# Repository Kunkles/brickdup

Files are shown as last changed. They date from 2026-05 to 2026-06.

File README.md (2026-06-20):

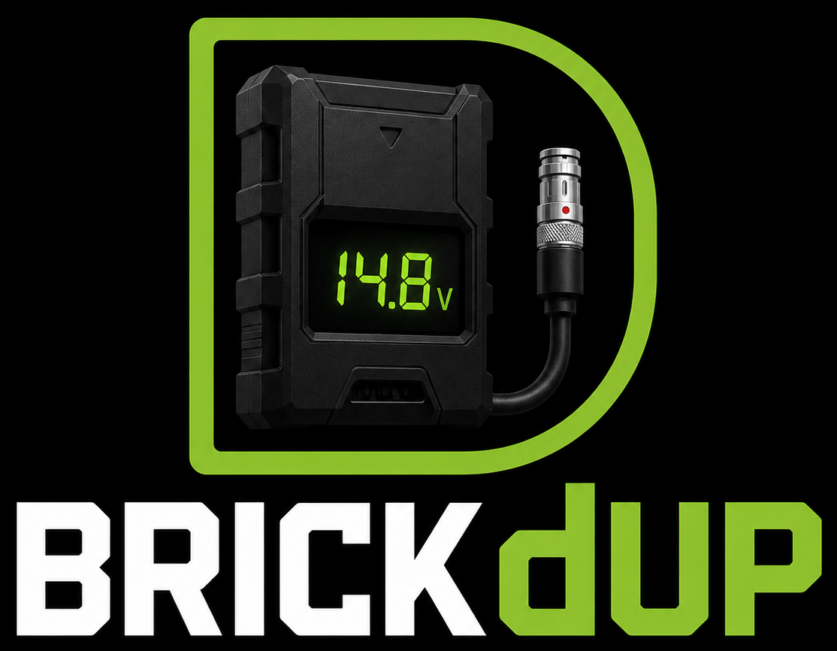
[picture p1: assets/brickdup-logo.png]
brickdup


# brickdup

Wireless battery voltage monitor for film/video sets. LoRa sensor nodes tap into camera batteries and broadcast readings to a handheld receiver with an e-ink display.

## Hardware

All boards: **Heltec WiFi LoRa 32 V3** (ESP32-S3 + SX1262, 915 MHz)

Receiver also has: **Waveshare 2.13" e-Paper HAT V4** (250×122, GDEY0213B74)

### Sensor node variants

| Variant | Battery | Connector | Voltage range | Divider |
|---|---|---|---|---|
| Onboard (`OB`) | 4S Li-Ion | D-Tap or AB 4-pin | up to 16.8V | R1=100kΩ, R2=22kΩ |
| Block (`BL`) | 6S Li-Ion | AB 4-pin (inline) | up to 25.2V | R1=180kΩ, R2=27kΩ |

Voltage divider feeds GPIO7. A 100nF ceramic cap between GPIO7 and GND filters ADC noise. Power the MCU through a buck converter (Pololu D24V10F5 — 36V max input, 5V out) tapped off VBAT. **Do not feed VBAT directly to the Heltec USB or VIN pin.**

📐 **Full wiring (both variants, with diagrams): [WIRING.md](WIRING.md)**
📌 **Pin assignments, button controls & screen layouts: [REFERENCE.md](REFERENCE.md)**
📝 **Firmware version history: [CHANGELOG.md](CHANGELOG.md)** — current: **v0.5.9**

### Pin map

```
LoRa SX1262 (HSPI):   CS=8, DIO1=14, RST=12, BUSY=13 | SCK=9, MISO=11, MOSI=10
ADC (sensor nodes):   VBAT_PIN = GPIO7 (ADC1_CH6)
E-ink (receiver):     CS=5, DC=4, RST=3, BUSY=2 | SCK=6, MOSI=1
```

## Sketches

| File | Flash to |
|---|---|
| **`sensor_universal_heltec_v3/`** | **Recommended** node firmware — one board, 4S **or** 6S, type selectable |
| `sensor_onboard_heltec_v3/` | Legacy onboard-only (4S) node |
| `sensor_block_heltec_v3/` | Legacy block-only (6S) node |
| `receiver_wireless_paper_v1_2/` | The handheld receiver (Heltec Wireless Paper) |
| `bench_ping_test/` | Both V3s, to verify the radio link (set `ROLE_PINGER` per board) |

**Universal node** (`sensor_universal_heltec_v3`) replaces the two single-mode
sketches: one universal divider (200k/22k as built — 2×100k + 22k — 6S-safe with headroom) and a runtime **battery
type** (OB 4S / BL 6S) that sets the thresholds + broadcast type. Pick it on the
config page or **long-press PRG** to toggle. Identical firmware on every node —
no per-unit edits. It shows a big 7-segment voltage and the type in the corner.

> **USB test mode:** the node sketches have `USB_TEST_MODE` (default `1`) that
> reads the board's onboard supply (~4V) instead of the divider, so the
> TX → RX → e-ink chain can be validated over USB-C with nothing wired. Set to
> `0` for real monitoring.

## Node identity

Every node has two names:

- **Permanent id** — auto-derived from the chip's unique MAC at boot. Never
  changes, guaranteed unique, and is the WiFi network name + the receiver's
  tracking key. The **universal** sketch uses a type-independent `ND-7F3A` (so
  toggling battery type updates the node in place); the legacy OB/BL sketches
  use `OB-7F3A` / `BL-7F3A`.
- **User name** — the friendly label you assign over WiFi (`Cam A`). Defaults to
  the permanent id until set. Shown on the OLED + handheld and broadcast.

Because the permanent id comes from the silicon, you flash the **same firmware to
every node** — no per-unit edits. With the universal sketch even the battery
type is a runtime setting, so one firmware truly covers every node.

## Packet format

```
T:<type>,I:<permId>,V:<voltage>,S:<status>[,B:<lipo>][,M:<name>]
```

Example: `T:OB,I:OB-7F3A,V:14.73,S:0,B:3.95,M:Cam A`

- `type` — `OB` or `BL`
- `permId` — permanent unique id (chip-derived), receiver's tracking key
- `voltage` — float, 2 decimal places
- `status` — 0=OK, 1=WARN, 2=CRIT, 3=no source (camera battery removed/dead)
- `lipo` — node bridge-LiPo voltage (optional; the node stays alive on it to report S:3)
- `name` — optional friendly name (no commas)

## Naming nodes (WiFi config portal)

Each node hosts a WiFi access point you can join to rename it — no reflashing:

1. Power the node and join WiFi **`Brickdup-OB-7F3A`** (password `brickdup`) —
   the suffix is unique per board, printed on the OLED at boot
2. Open **http://192.168.4.1**
3. Type a **name**, tap Save

The name persists in flash (survives reboot/reflash) and rides along in every
packet, so the handheld shows it automatically.

**Turning WiFi off (saves ~80mA):** no extra hardware needed —

- Tap the node's onboard **PRG button** any time to toggle WiFi on/off, or
- Hit **Turn off WiFi** on the config page when you're done naming.

Press PRG again to bring it back. The on/off choice is **remembered across
reboots** — a node switched off stays off after a power cycle. `WIFI_ON_AT_BOOT`
is only the first-ever-boot default.

## Button controls

| Unit | Single tap | Long press | Triple tap |
|---|---|---|---|
| Node (PRG) | toggle WiFi | — | **power off** |
| Receiver (USER) | page nodes | toggle dashboard | **power off** |

"Power off" is deep sleep (~10–20µA); the screen shows **POWERED DOWN** (white
on black), then **press the button again to wake** (the unit reboots). The
receiver e-ink keeps the POWERED DOWN screen visible while asleep.

Thresholds (defaults, editable per type in the node portal) — Onboard: WARN=13.5V, CRIT=12.8V | Block: WARN=21.0V, CRIT=20.0V

## Radio config

```
Frequency: 915.0 MHz  |  Bandwidth: 125 kHz  |  SF: 9  |  CR: 4/5
Sync word: 0xAB       |  TX power: 17 dBm    |  Preamble: 8
```

All nodes must use identical settings. SF9 gives 50–100m range with obstacles. Up to 12 nodes, 10s interval — no collision concern.

## Build environment

**Arduino IDE 2.x** with the **Heltec ESP32 board package** (Board Manager URL):
```
https://resource.heltec.cn/download/package_heltec_esp32_index.json
```

**Board selection differs per sketch** (the e-ink library requires the exact
board, or it errors with "Wrong build env"):

| Sketch | Tools → Board |
|---|---|
| `receiver_wireless_paper_v1_2` | **Wireless Paper** (search "paper") |
| `sensor_universal_heltec_v3` | Heltec WiFi LoRa 32(V3) |
| `sensor_onboard_heltec_v3` | Heltec WiFi LoRa 32(V3) |
| `sensor_block_heltec_v3` | Heltec WiFi LoRa 32(V3) |

Common settings: USB CDC On Boot → **Enabled** | Upload Speed → 921600

**OTA updates (no USB after the first flash):** every unit's web portal has a
`/update` page. Build a `.bin` via **Sketch → Export Compiled Binary**, join the
unit's WiFi, open its `/update` page (linked from the config page / dashboard),
and upload the matching `.bin` — it flashes the spare partition, verifies, and
reboots. Upload the OB `.bin` to onboard nodes, BL to block nodes, receiver to
the receiver (the page shows which it expects).

> No partition setting needed: the Heltec WiFi LoRa 32 V3 and Wireless Paper
> both default to the `default_8MB` scheme, which already has two ~3.3MB app
> slots (OTA-capable). There's no "Partition Scheme" menu for these boards
> because the partition is fixed — and it's the right one.

### Prebuilt firmware (CI)

GitHub Actions compiles all three sketches on **every push** and on version
tags — no local toolchain needed to get a `.bin`:

- **Every push:** download `brickdup-firmware` from the
  [latest Actions run](../../actions) (artifacts: `brickdup_onboard.bin`,
  `brickdup_block.bin`, `brickdup_receiver.bin`).
- **Tagged releases:** push a `vX.Y.Z` tag → the `.bin`s are attached to a
  [GitHub Release](../../releases).

Grab the matching `.bin` and push it to a unit via its `/update` page. To cut a
release: bump `FW_VERSION` in all three sketches, update `CHANGELOG.md`, commit,
then `git tag v0.5.1 && git push --tags`.

**Libraries (Library Manager):**
- `RadioLib` by Jan Gromeš — all three sketches
- `Heltec ESP32 Dev-Boards` by Heltec — node OLED (`HT_SSD1306Wire.h`)
- `heltec-eink-modules` by todd-herbert — receiver e-ink (pulls in Adafruit GFX)

## BOM

| Part | Source | ~Cost |
|---|---|---|
| Heltec WiFi LoRa 32 V3 (915 MHz) — nodes | Amazon | $22 ea |
| Heltec Wireless Paper (915 MHz) — receiver | Amazon | $22 |
| Pololu D24V10F5 buck converter (per node) | Pololu | — |
| Node LiPo — MakerHawk 1100mAh 1S (JST 1.25) | Amazon `B0F9YSFV4T` | 4-pack |
| Receiver LiPo — MakerFocus 3000mAh 1S (JST 1.25) | Amazon `B08T6GT7DV` | 4-pack |
| D-Tap male connectors | B&H (CT-DTAP-M) | — |
| AB 4-pin connectors | Pinknoise Systems / Trew Audio | — |
| 1% metal film resistors — universal: 200k, 27k (legacy: 100k/22k, 180k/27k) | — | — |
| 100nF ceramic caps (104) | — | — |

## Roadmap

- [x] Bench ping test (verify radio link before analog wiring)
- [x] Receiver paging (USER button cycles pages when >5 nodes)
- [x] Fuel gauge: SoC % + rough time-to-empty per node (voltage-based)
- [x] Calibration (enter true voltage on the web page; gain factor saved to NVS)
- [x] RSSI signal bars per node on the receiver
- [x] Receiver web dashboard (live node table on your phone; long-press USER)
- [x] OTA firmware update via the web portal on all units (/update page)
- [x] Captive portal — config page auto-pops on WiFi connect
- [x] Universal node — one sketch, runtime 4S/6S battery type (web or long-press)
- [x] Prebuilt firmware via CI (GitHub Actions builds .bin on every push)
- [ ] Channel/group selection — separate networks via distinct frequency +
      sync word per channel, set on the node web page and on the receiver,
      NVS-stored. Lets multiple brickdup systems coexist (e.g. 1st/2nd unit)
- [ ] WiFi client (STA) mode — units optionally join a local network (DHCP or
      static IP) instead of hosting their own AP, each reachable at a unique
      mDNS host like `brickdup-7f3a.local` (chip-serial based).
      Credentials set via the AP config page, stored in NVS. Reach/OTA any unit
      from one device on the production WiFi
- [ ] Trusted WiFi networks — a saved list of known SSIDs the unit auto-joins
      (STA) when one is in range and WiFi is on, falling back to its own AP
      otherwise. Set via the config page, stored in NVS
- [ ] BLE / companion phone app — receiver exposes node data over Bluetooth LE
      (GATT, mirroring the `/data` JSON) for a phone app: live view + push
      notifications for CRIT/DEAD batteries (alerts even with the handheld in a
      bag), no WiFi join needed. NimBLE stack; LoRa is a separate radio, BLE
      time-shares 2.4GHz with WiFi
- [ ] iOS app — native companion that keeps a **persistent live readout** of all
      nodes and fires **push/local notifications** on CRIT/DEAD/LOST (even when
      backgrounded or the phone is locked). Connects via BLE (Core Bluetooth
      background mode) to the receiver; the front-end for the BLE item above
- [ ] Bridge LiPo on nodes — small backup cell (buck keeps it charged) so a node
      stays alive to report a **camera battery removed/dead for sure** (vs just
      going silent), survives swaps, and reports its own LiPo level. Replaces the
      receiver's inferred DEAD with an explicit reported one
- [ ] VCLX block-battery mode (NiMH) — the blocks in use are Anton/Bauer
      **VCLX NM2** (600Wh **NiMH**), tapped at a 14.4V 4-pin XLR. Per the
      [manual](https://www.antonbauer.com/wp-content/uploads/2023/07/ab_86750174-4980_0-vclx_nm2-manual_en.pdf)
      spec table, only 28V/48V (+5V USB) are regulated; the 4-pin XLRs are
      **variable 12–17V** (pack-following) — so the node *does* see a real
      discharge curve. But the chemistry breaks the Li-ion fuel gauge: NiMH
      holds a flat ~14.4V (1.2V/cell × 12) for most of the discharge, knees
      at ~13.2V, and the battery hard-cuts its output at **12.0V** (output
      vanishes → bridge LiPo keeps the node alive to report DEAD). Repurpose
      BL mode → NiMH profile: thresholds ≈ WARN 13.2 / CRIT 12.4, and
      suppress SoC%/time-to-empty (or fit a rough NiMH curve) — the Li-ion
      curve reads nonsense on the flat middle. Verify thresholds on a real
      pack: meter the XLR full (~16.8V) vs drained. Heads-up for the divider
      bench test: cap input at ~17V for this mode, not 25.2V
- [ ] CRIT buzzer alert on receiver
- [x] NVS persistence — receiver remembers nodes across reboots (clear on dashboard)
- [ ] Deep sleep on sensor nodes (~10µA between transmissions)
- [ ] PCB design (sensor node, two variants or DNP options)

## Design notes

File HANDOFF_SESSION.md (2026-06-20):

# brickdup — Session Handoff

Context document for continuing work in a fresh session. Read this plus the
repo docs (README, WIRING, REFERENCE, ENCLOSURE, CHANGELOG) and you have the
full picture.

---

## What this project is

**brickdup** — a LoRa wireless battery-voltage monitor for film/video sets.
Sensor nodes tap into camera batteries (4S "onboard" bricks or 6S "block"
batteries) and broadcast readings to a handheld receiver with an e-ink display.
The user (Ryan) is a film-industry tech (DIT-adjacent) building this for real
on-set use.

- **Repo:** https://github.com/Kunkles/brickdup (local: `~/Documents/brickwatch/`
  — folder name predates the repo rename, that's fine)
- **Firmware version:** v0.5.9 (`FW_VERSION` in each sketch; CHANGELOG.md)
- **CI:** GitHub Actions builds all sketches on every push; artifacts =
  `brickdup_{universal,onboard,block,receiver}.bin`. Tags `v*` attach bins to a
  GitHub Release.

## Hardware on hand

| Unit | Board | Role |
|---|---|---|
| 2× nodes | Heltec WiFi LoRa 32 V3 (915MHz, ESP32-S3 + SX1262, 0.96" OLED) | sensor nodes |
| 1× receiver | Heltec **Wireless Paper** V1.2 (ESP32-S3 + SX1262 + 2.13" e-ink) | handheld |
| Node LiPo | MakerHawk **1100mAh** 1S JST1.25 (`B0F9YSFV4T`) — **41.4×25.15×10.25mm** (calipered) | bridge cell |
| Receiver LiPo | MakerFocus **3000mAh** 1S JST1.25 (`B08T6GT7DV`) — **65×35×10mm** | solo all-day |
| Bench supply | SPS-3010 series 0–30V/10A | for divider testing |
| Buck (per node) | Pololu D24V10F5 (36V→5V 1A) | powers node + charges LiPo |

**Arduino IDE 2.x**, Heltec board package (3.3.8, URL in README). Board per
sketch: receiver = "Wireless Paper" (the eink lib hard-requires it — "Wrong
build env" error otherwise), nodes = "Heltec WiFi LoRa 32(V3)". USB CDC On
Boot = Enabled. Libraries: RadioLib, Heltec ESP32 Dev-Boards (`HT_SSD1306Wire.h`),
heltec-eink-modules (todd-herbert). Region menu → US915 (cosmetic; freq is
hardcoded 915.0).

## Architecture / key design decisions

- **Radio:** 915.0MHz, BW125, SF9, CR4/5, sync 0xAB, 17dBm, preamble 8 — must
  match across all units. TX every 10s.
- **Packet (ASCII):** `T:<OB|BL>,I:<permId>,V:<float>,S:<0|1|2|3>[,B:<lipo>][,M:<name>]`
  (S:3 = no source / battery removed-dead; B: = node bridge-LiPo volts)
- **Identity:** permanent id from chip MAC. Universal sketch uses
  **`ND-XXXX`** (type-independent so toggling 4S/6S doesn't spawn a ghost
  node); legacy sketches use `OB-`/`BL-`. The id IS the WiFi AP name
  (`Brickdup-ND-XXXX`, password `brickdup`, portal at 192.168.4.1). User-
  assignable friendly name (≤10 chars, NVS) rides in `M:` and wins on display.
- **Universal node** (`sensor_universal_heltec_v3/`) is the recommended node
  firmware: one divider **200k/22k** (2×100k + 22k as built; 6S-safe, 25.2V→~2.5V on GPIO7), battery
  type is a runtime setting (web dropdown or long-press PRG) that flips
  thresholds (OB: WARN 13.5/CRIT 12.8 · BL: WARN 21.0/CRIT 20.0 — defaults, now editable per type in the portal, NVS) and broadcast
  type. Legacy `sensor_onboard`/`sensor_block` kept for reference.
- **Node power architecture (DONE in fw 0.5.3):** camera battery → buck →
  Heltec 5V pin (powers board + charges bridge LiPo via onboard charger);
  camera battery also → divider → GPIO7 (sense, common ground). The 1100mAh
  LiPo bridges swaps and keeps the node alive to **report** a removed/dead
  camera battery: node reads its LiPo (B:<v>) and sends S:3 ("no source") when
  the camera reading <5V; receiver shows explicit DEAD + the Li level (vs the
  older silent-after-CRIT *inferred* DEAD, still supported).
- **Bench/demo flags now OFF for real monitoring:** universal sketch has
  `USB_TEST_MODE 0` and `DEMO_VOLTAGE_ON 0` — it reads the real divider on
  GPIO7 (via `analogReadMilliVolts`). Set `USB_TEST_MODE 1` only to re-run the
  no-divider USB bench test. Receiver has `DEMO_NODES` (currently 0).

## Feature inventory (all working, v0.5.9)

**Nodes:** OLED status (id/SSID top, name, big 7-segment voltage with narrow
"1" + GAP 6, emboldened "V", type + version bottom), WiFi config portal
(captive — auto-pops on join) with rename / battery type / single-point
calibration (gain factor in NVS) / WiFi-off / OTA `/update`, PRG button:
tap = WiFi toggle, long-press = 4S↔6S (big confirmation flash), triple-tap =
power off (deep sleep, "POWERED DOWN" screen, press to wake). WiFi state
persists across reboots.

**Receiver:** e-ink list (5/page, USER button pages), header = BRICKDUP +
version + page + own battery (+ = charging, trend-based; ADC2 GPIO20/ctrl 19
can't read while WiFi on — holds last value; optional `VBUS_PIN` define for
wired USB detect), per-node rows = name (10 char, "..." truncation), SoC% +
~time-to-empty (Li-ion curve, 100%=full, 0%=CRIT), 1-decimal voltage, 3-bar
RSSI (≥-95/-110/-120), states OK/WARN/CRIT (inverted bar) / STALE (15s) /
LOST (28s, flashes via fastmode) / DEAD (steady — silent-after-CRIT
inference). Long-press = WiFi dashboard (captive, live table polling /data
JSON every 2s, Clear-node-list, OTA link), triple-tap = power off. Node
roster persists in NVS (~2min throttle). DNSServer captive portal on all
units.

## Roadmap (README has full text)

Done: ping test, paging, fuel gauge, calibration, RSSI bars, dashboard, OTA,
captive portal, universal node, CI, NVS roster, bridge-LiPo firmware
(explicit removed/dead reporting + node LiPo level, fw 0.5.3).
**Open:** channel/group selection (freq+syncword sets), WiFi STA mode + mDNS,
trusted-WiFi auto-join list, BLE + **iOS app** (persistent readout + CRIT/DEAD
notifications, Core Bluetooth background), **VCLX/NiMH block mode** (thresholds
+ honest fuel gauge — needs meter verification), CRIT buzzer (needs piezo),
deep sleep, PCB (universal, screw
terminals, buck+divider integrated). Also promised: a **user manual** at some
point (user asked; deferred until features settle).

## Conventions / user preferences

- Commit style: imperative summary + body, trailer
  `Co-Authored-By: Claude <model> <noreply@anthropic.com>`. Push after every
  change ("update the git repo" = check clean/pushed).
- User prefers: web-portal config over recompiling, zero per-unit firmware
  edits, physical-button UX (taps/long-press), visible feedback for every
  action (e.g. the type-toggle confirmation flash), honest caveats about
  accuracy/limitations, short friendly names (10 char cap), green `#2dd47a`
  accent + black backgrounds on web pages (logo embedded as
  `brickdup_logo.h`, served at `/logo.jpg`).
- Iterate in small steps with hardware verification between (user flashes +
  reports); compile errors get pasted back — fix and push.
- Diagrams: clean SVG schematics (boxes, junction dots, common ground rail,
  GitHub light/dark-safe colors), saved to `docs/` and embedded in the
  relevant doc — not ASCII art, not chat-only. See `docs/node_wiring.svg`.
- Display tweaks went through several rounds (7-seg digits, narrow 1, GAP 6,
  small bold V) — current state is liked; don't redesign unprompted.

## Known gotchas

- e-ink lib needs exact board selected; `getTextBounds` works but
  `drawFastHLine` doesn't exist — use `drawLine`/`fillRect`.
- OLED needs Vext (GPIO36 LOW) before init; fonts only 10/16/24pt (hence
  custom 7-seg renderer `drawVoltage7`/`drawDigit7`; unused `drawV7` still in
  file).
- GPIO0 = boot strap: never *hold* during reset/wake.
- ESP32-S3 ADC2 (receiver battery GPIO20) conflicts with WiFi.
- Universal divider top end (200k/22k): 6S full = ~2.5V on GPIO7 — fine; legacy BL
  180k/27k ran 3.29V (tight, documented).
- Heltec boards.txt hardcodes `default_8MB` partitions (OTA-capable app0/app1,
  no Partition Scheme menu — that's fine).
- Receiver SSID `Brickdup-RX-XXXX`; nodes `Brickdup-ND-XXXX` (universal).
- CI artifact name: `brickdup-firmware`.

## Immediate next steps (where we left off)

1. User may want an **OpenSCAD starter scaffold** for the enclosures (offered,
   not yet accepted). ENCLOSURE.md has all parameters; battery dims measured
   and recorded; board dims still `‹MEASURE›`.
2. Before real deployment: set `DEMO_VOLTAGE_ON 0` (universal),
   `USB_TEST_MODE 0` (when divider wired), calibrate via portal, bench-test
   divider with the 0–30V supply (WIRING.md procedure).
3. Bridge-LiPo firmware (explicit DEAD reporting) is the next meaty firmware
   task when user is ready.

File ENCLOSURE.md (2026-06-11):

# brickdup — 3D-Printable Enclosure Design Brief

A complete brief for designing 3D-printable enclosures for the brickdup system.
Written so an LLM or CAD tool can produce parametric models (OpenSCAD,
Fusion 360, etc.). **Dimensions marked `‹MEASURE›` must be confirmed with
calipers before cutting final tolerances** — verify against the actual hardware.

There are **two enclosures**:
1. **Sensor node** — rugged, mounts on/near a camera battery, powered by that
   battery (no internal cell). Survives a set.
2. **Receiver (handheld)** — pocketable, e-ink window, internal LiPo, button
   access. The "remote" you carry.

---

## 0. Global design parameters (use as variables)

| Parameter | Default | Notes |
|---|---|---|
| `wall` | 2.0 mm | Wall thickness (PETG/PLA) |
| `tol_slip` | 0.20 mm | Clearance for slip-fit parts |
| `tol_press` | 0.10 mm | Clearance for press-fit |
| `fillet` | 1.5 mm | Edge rounding |
| `screw` | M2 or M2.5 | Self-tapping into bosses, or heat-set inserts |
| `pcb_standoff` | 3 mm | Height of PCB support ribs/bosses |
| Print material | **PETG** preferred | Tougher/heat-tolerant than PLA; on-set durability + WiFi warmth |
| Orientation | Lid/base split | Design for supportless printing where possible |

**General rules**
- Two-part shell: **base + lid**, joined by **M2 screws into bosses** (preferred
  for serviceability) or snap-fit clips.
- All board-edge ports get cutouts sized `port + tol_slip` on each side.
- Add **0.4–0.6 mm chamfers** at USB/connector mouths so cables seat easily.
- Provide **internal ribs/bosses** to locate the PCB and stop it sliding.
- The nodes run warm when WiFi is on — include **vent slots** (see §3).

---

## 1. Components to house

### Heltec WiFi LoRa 32 V3 (both node and receiver use this MCU family)
| Item | Value | Notes |
|---|---|---|
| PCB L × W | **≈ 50.2 × 25.5 mm** `‹MEASURE›` | |
| PCB thickness | ≈ 1.0 mm | |
| Tallest component height | ≈ 8–10 mm `‹MEASURE›` | OLED + USB dominate |
| USB-C port | one short end, centered | for charging/flashing |
| 0.96" OLED | top face, ~21.7 × 11 mm active `‹MEASURE›` window | node only |
| Buttons | RST + PRG/USER near USB end | **PRG must be pressable** (see §4) |
| LoRa antenna | u.FL/IPEX connector on PCB edge → external antenna | route a pigtail out |
| LiPo JST | 1.25 mm 2-pin connector (on V3) | |

### Heltec Wireless Paper (receiver)
| Item | Value | Notes |
|---|---|---|
| PCB + e-ink module | **`‹MEASURE›`** (≈ 2.13" panel; roughly 60–65 × 30–35 mm) | |
| e-ink active area | **250 × 122 px ≈ 48.5 × 23.7 mm** `‹MEASURE›` | the display window |
| USB-C | one end | charging/flashing |
| USER button | GPIO0, on-board | **must be pressable** |
| LoRa antenna | u.FL → external | |
| Internal LiPo | see below | |

### Internal LiPo (1S, JST 1.25) — **sized per role**

Both units take a 1S LiPo (MakerFocus, protection board, JST 1.25 plug), but the
**capacity differs by role** because the battery does a different job in each:

| Unit | Cell (chosen) | Why |
|---|---|---|
| **Node** | **MakerHawk 1100 mAh** 1S (Amazon `B0F9YSFV4T`) | The LiPo is a **bridge/backup**, not primary power — the buck tops it off from the camera battery whenever one is connected. It only carries the node through a swap (seconds) or the window after a camera battery dies (minutes). Solo runtime is still ~15 h. **Smaller = more compact node.** |
| **Receiver** | **MakerFocus 3000 mAh** 1S (Amazon `B08T6GT7DV`) | Runs **solo all day** — nothing tops it off. ~3000 mAh ≈ 1+ day with margin for dashboard use. |

Both are 1S LiPo pouches with a protection board and a **JST 1.25 plug** that mates
the Heltec battery connector directly (no adapter).

| Item | Value | Notes |
|---|---|---|
| **Node cell** (1100 mAh) | **41.4 × 25.15 × 10.25 mm** (L × W × thick, calipered) | pocket: 42 mm clear span between towers, tape-retained, no end stop |
| **Receiver cell** (3000 mAh) | **65 × 35 × 10 mm** (L × W × thick) | pocket ≈ **67 × 37 × 11 mm** (+1 mm clearance) |
| Mounting | flat pocket, tape or retention lip | keep clear of the antenna |

> Both cells are **10 mm thick** — that sets the minimum internal depth of each
> shell's battery pocket. Add the JST plug + strain relief on the lead end
> (~+2 mm length). Pocket lengths above already include +1 mm all-round slip.

> ⚠️ **The LiPo is the biggest size driver for each shell.** Measure the exact
> cell you'll use, then design the pocket around it (+1 mm clearance all round,
> +2 mm on the lead side for the JST plug + strain relief). Never compress a
> pouch cell — give it a flat, unstressed bed.

---

## 2. Sensor-node enclosure

> **Parametric model:** [`enclosure/node_enclosure.scad`](enclosure/node_enclosure.scad)
> implements this section (**stacked + side-channel** layout: LiPo flat on
> the floor, Heltec on 13 mm towers above it and ~2.5 mm from the west wall
> so USB-C is a normal chamfered port hole; side channels carry the buck +
> wiring and host the four internal M2 corner bosses; east bay for the LEMO
> tail + divider; outer ≈ **68 × 54 × 24 mm**). Open in OpenSCAD, set
> `part`, tweak the `MEASURE`-tagged
> variables after calipering. Assumes no bottom-facing pin headers on the
> Heltec; if soldered, raise `standoff_h` (shell grows taller). PRG/RST are
> actuated via **captive printed plungers** (guide tube in the lid + printed
> piston, §4) — no exposed PCB; set `plungers = false` for plain holes.

Houses: **Heltec V3** + the **buck converter** (Pololu D24V10F5, ~12.7 × 10.2 mm
`‹MEASURE›`) + the **voltage divider + cap** + a **small bridge LiPo (~1100 mAh)**
+ wiring to the **battery connector** (**LEMO panel-mount** — chosen over
D-Tap/AB; measure your shell's panel-hole diameter + key flat).

> **Power architecture:** the camera battery → buck → 5V powers the node *and*
> charges the LiPo; the camera battery is also sensed via the divider → GPIO7.
> The LiPo **bridges** battery swaps and keeps the node alive to report a dead /
> removed camera battery for sure (vs just going silent). So the node needs a
> **small LiPo pocket** in addition to the buck + divider bays.

**Required features**
- **OLED window** on the top face (clear cutout or thin transparent insert), over
  the 0.96" OLED.
- **PRG button access** — a hole, flexible membrane, or a printed plunger button.
- **USB-C cutout** (flashing + charging the bridge LiPo).
- **Bridge LiPo pocket** — flat bed for the ~1100 mAh cell, JST reachable, away
  from the antenna; tape or a retention lip (never compress the pouch).
- **LoRa antenna exit** — a hole/grommet for the u.FL pigtail + external antenna,
  or an SMA bulkhead cutout if using a panel-mount antenna.
- **Battery-lead entry** — a strain-relieved cutout/grommet where the wires from
  the D-Tap/AB connector enter (these carry VBAT to the buck + divider).
- **Mounting** — pick one (make it a swappable module):
  - flat back with a **velcro/strap channel** (battery mount on set), and/or
  - **¼"-20 or 3/8" threaded insert** boss, and/or
  - **AB/D-Tap connector** panel-mount face.
- **Vent slots** near the buck + ESP for WiFi-mode warmth (see §3).
- **Internal bays:** locate the Heltec, a footprint for the buck, and a small bay
  for the divider board, with wire channels between them.

**Voltage divider — plan the bay around your build method.** The divider is tiny
(R1 = 200kΩ, R2 = 27kΩ, + 100 nF cap, on GPIO7), but its footprint depends on how
it's assembled — design the bay for whichever you use:
- **Inline (smallest):** components soldered inline and heat-shrunk — no board.
  Just provide a **wire channel + a ~10 × 25 mm slack pocket** between the
  battery-lead entry and the Heltec.
- **Perfboard scrap:** allow a **~20 × 15 mm board bay** (`‹MEASURE your board›`)
  with a locating lip.
- **Future PCB:** the planned sensor PCB **combines the buck + divider** on one
  board — then this becomes a single board footprint (size TBD by the PCB).

Keep the divider node (GPIO7) and its 100 nF cap **close to the Heltec** to keep
the ADC trace short and quiet.

**Suggested envelope:** ~60 × 35 × 20 mm internal `‹DERIVE from parts›`. Rugged,
thick corners, IP-ish (gasket channel optional).

---

## 3. Thermal / ventilation

WiFi-on draws ~80–150 mA and warms the ESP + regulator (~40–50 °C). LoRa-only is
cool. Include modest passive venting so a sealed unit doesn't bake during config:
- **Slots** (≥1 mm, label-side or bottom) above the ESP module and buck.
- Keep vents **off the top display face** (debris/water).
- Receiver: less critical (WiFi usually off), but a few slots near the ESP help.

---

## 4. Buttons & display access

- **Buttons (GPIO0 / PRG / USER):** the button is a small SMD tactile on the PCB.
  Provide **a printed flexible plunger** (living hinge or a separate TPU button)
  aligned to it, OR a simple access hole. The button is used a lot (WiFi toggle,
  long-press = battery type, triple-tap = power off), so make it **easy and
  reliable**. `‹MEASURE button XY position from a board reference corner›`.
- **OLED / e-ink window:** flush cutout, or recess + thin clear acrylic/PETG
  window (0.5–1 mm) glued/captured. e-ink needs no backlight; a flush window is
  fine. Align precisely to the active area `‹MEASURE offsets›`.

---

## 5. Antenna

- The LoRa antenna is **external** (u.FL pigtail to a wire/SMA antenna). **Do not
  bury the antenna inside a closed cavity against the PCB ground or battery** —
  route it out of the shell. Provide a **u.FL pigtail exit hole** or an **SMA
  bulkhead** cutout (SMA nut ≈ 6.5 mm hole `‹VERIFY›`).
- Keep the antenna run away from the LiPo and large metal.

---

## 6. Assembly & serviceability

- **Base + lid**, M2 screws into 4 corner bosses (heat-set inserts preferred for
  repeated opening) — these get opened to swap antennas, reflash via USB, etc.
- PCB held by standoffs/bosses + a retaining lip; no glue on the board.
- Receiver: LiPo in a taped pocket, leads strain-relieved, JST reachable.
- Leave **finger clearance** to unplug USB and the JST.

---

## 7. Print settings (recommended)

- **Material:** PETG (PLA acceptable for cool/indoor use).
- **Walls:** 3 perimeters; **Infill:** 20–30 % (gyroid).
- **Layer:** 0.2 mm.
- **Tolerance test first:** print a small fit-test of the USB cutout + a PCB-edge
  slot before the full shell.

---

## 8. Measurements to take before finalizing (checklist)

Take these with calipers off the real hardware and fill into the parameters:

- [ ] Heltec V3 PCB L × W × thickness; height of tallest component
- [ ] OLED active-area size + its X/Y offset from a PCB corner
- [ ] PRG & RST button X/Y positions + height
- [ ] USB-C cutout width/height + offset from PCB edge
- [ ] u.FL connector position (antenna exit)
- [ ] Wireless Paper module overall L × W × thickness
- [ ] e-ink active-area size + X/Y offset
- [ ] USER button + USB-C positions on the receiver
- [x] Node LiPo (1100 mAh): **40 × 25 × 10 mm** (+ lead length ‹measure›)
- [x] Receiver LiPo (3000 mAh): **65 × 35 × 10 mm** (+ lead length ‹measure›)
- [ ] Buck (D24V10F5) footprint + height; divider board size
- [ ] LEMO connector: panel-hole diameter + key-flat dims, body depth behind
      panel, boot/strain-relief length

---

## 9. Acceptance criteria

A good design:
- Closes with the PCB located, no rattle, no stress on the e-ink/OLED.
- USB, button, antenna, and (node) battery leads all accessible without opening.
- LiPo (receiver) sits flat and unstressed with the JST reachable.
- Opens with hand tools for reflash/service.
- Survives a drop from cart height (corners + PETG).
- Vents enough that a WiFi-on session doesn't overheat.

---

*Hardware reference: see [REFERENCE.md](REFERENCE.md) (pins, board roles) and
[WIRING.md](WIRING.md) (node power/sense wiring).*

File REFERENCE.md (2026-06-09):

# brickdup — Pin & Controls Reference

Quick reference for every pin assignment and button gesture across the three
firmwares. For sensor-node *wiring* (dividers, buck, connectors) see
[WIRING.md](WIRING.md).

---

## Pin assignments

### Sensor nodes — Heltec WiFi LoRa 32 V3 (`OB` and `BL`)

| Function | Pin(s) |
|---|---|
| **LoRa SX1262** (HSPI) | CS=8, DIO1=14, RST=12, BUSY=13 · SCK=9, MISO=11, MOSI=10 |
| **VBAT sense** (real mode) | GPIO7 — external divider midpoint (ADC1) |
| **Onboard battery sense** (USB test mode) | ADC=GPIO1, enable=GPIO37 (drive LOW), factor ≈0.0041 |
| **OLED** (I²C, 128×64) | SDA=17, SCL=18, RST=21 |
| **OLED power rail** (Vext) | GPIO36 — drive LOW = on |
| **USER / PRG button** | GPIO0 |
| **External 5V input** | `5V` pad (from the buck — never raw VBAT) |

Divider resistors: **universal** R1=200k/R2=27k (covers 4S & 6S) · legacy
**OB** R1=100k/R2=22k · **BL** R1=180k/R2=27k.

### Receiver — Heltec Wireless Paper

| Function | Pin(s) |
|---|---|
| **LoRa SX1262** (HSPI) | CS=8, DIO1=14, RST=12, BUSY=13 · SCK=9, MISO=11, MOSI=10 |
| **E-ink** (internal, library-handled) | RST=6, DC=5, CS=4, BUSY=7, SCK=3, MOSI=2 |
| **E-ink power rail** (Vext) | GPIO45 — active low |
| **Own battery sense** | ADC=GPIO20 (ADC2), enable=GPIO19 (drive LOW), ×2 divider |
| **USER button** | GPIO0 |
| **VBUS / USB-present detect** *(optional)* | `VBUS_PIN` = `-1` (unset). Wire 5V→divider→spare GPIO, set the define |
| **Power LED** | GPIO18 (unused by firmware) |

> ADC2 (battery) can't be read while WiFi is active, so the receiver holds its
> last battery reading while the dashboard is up.

### Radio config (identical on all units)

```
915.0 MHz · 125 kHz BW · SF9 · CR 4/5 · sync 0xAB · 17 dBm · preamble 8
```

---

## Button controls

Both boards use the onboard button on **GPIO0**.

### Sensor nodes (PRG button)

| Gesture | Action |
|---|---|
| **Single tap** | Toggle the WiFi config portal on/off |
| **Long press** (~1s) | *(universal sketch)* toggle battery type 4S ↔ 6S |
| **Triple tap** | Power off (deep sleep ~10–20µA) — press the button again to wake |

WiFi on/off, "off", and battery type are remembered across reboots (NVS). The
legacy OB/BL sketches have no long-press (type is fixed per sketch).

### Receiver (USER button)

| Gesture | Action |
|---|---|
| **Short tap** | Page through nodes (5 per page) |
| **Long press** (~1.2s) | Toggle the web dashboard WiFi |
| **Triple tap** | Power off (deep sleep) — press the button again to wake |

> GPIO0 is the boot-strap pin — don't *hold* the button while a unit powers up
> or wakes (that enters bootloader). A normal tap is fine.

---

## On-screen layout

### Node OLED (universal sketch)

```
ND-7F3A                   OK     ← WiFi network name / id (left) · status (right)
Cam A                            ← user name
┌─┐ ┌─┐ . ┌─┐  V          OB 4S  ← big 7-segment voltage · battery type (right)
                          v0.5.0 ← firmware version (bottom-right)
```

- Top-left shows the full `Brickdup-ND-7F3A` SSID when WiFi is on, else just `ND-7F3A`.
- Battery type sits where `USB TEST` appears in test mode (right column).
- Long-press flashes a big `OB 4S` / `BL 6S` confirmation.
- "POWERED DOWN" (white on black) shows briefly on triple-tap before sleep.

### Receiver e-ink

```
BRICKDUP v0.5.0  2/3       4.1V  ← title · version · page (if >1) · battery (+ = charging)
──────────────────────────────
█ Cam A    63% ~48m   14.2V ▂▄█  ← marker · name · %/ETA · voltage · signal
  Cam B    88% ~2.1h  15.6V ▂▄░
  Cam C  stale        14.0V ▂░░
  Cam D              *DEAD*       ← silent after CRIT = battery dead (steady)
  Cam E              *LOST*       ← silent while healthy (flashes)
WiFi: Brickdup-RX-7F3A           ← AP name shown bottom-left when dashboard on
```

Per-node states: **OK / WARN / CRIT / STALE / DEAD / LOST**. CRIT and DEAD are
steady inverted bars; LOST flashes. "POWERED DOWN" fills the screen (white on
black) on triple-tap and stays visible while asleep (e-ink holds the image).

---

## Web portals

| Unit | AP name | Pages |
|---|---|---|
| Node | `Brickdup-OB-<id>` / `Brickdup-BL-<id>` | `/` config (name, calibrate), `/update` OTA |
| Receiver | `Brickdup-RX-<id>` | `/` dashboard (clear list, OTA link), `/update` OTA |

Password: **`brickdup`** · address: **http://192.168.4.1**
The `<id>` suffix is unique per board (chip serial) and shown on its display.

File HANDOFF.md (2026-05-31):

# LoRa Battery Monitor — Project Handoff

## Project goal

Build a LoRa-based wireless battery voltage monitoring system for use on film/video sets. Multiple sensor nodes tap into different battery types and broadcast voltage readings to a single handheld receiver with an e-ink display.

## System architecture

- **Sensor nodes** (one per battery being monitored) — read voltage via ADC, transmit packets over LoRa every 10 seconds, then sleep
- **Receiver** (handheld) — listens continuously, tracks all nodes, displays current state on e-ink

Two variants of sensor node:

| Variant | Battery | Connector | Voltage range | Divider |
|---|---|---|---|---|
| Onboard (`OB`) | 4S Li-Ion | D-Tap or AB 4-pin | up to 16.8V | R1=100kΩ, R2=22kΩ |
| Block (`BL`) | 6S Li-Ion | AB 4-pin (inline) | up to 25.2V | R1=180kΩ, R2=27kΩ |

## Hardware

All boards: **Heltec WiFi LoRa 32 V3** (ESP32-S3 + SX1262, 915 MHz)

Receiver also has: **Waveshare 2.13" e-Paper HAT V4** (250×122, SPI, GDEY0213B74 controller)

### Pin map (Heltec V3 — same on every board)

```
LoRa SX1262 (HSPI):
  CS=8, DIO1=14, RST=12, BUSY=13
  SCK=9, MISO=11, MOSI=10

ADC (sensor nodes only):
  VBAT_PIN = GPIO7 (ADC1_CH6)

E-ink (receiver only, uses default SPI):
  CS=5, DC=4, RST=3, BUSY=2
  SCK=6, MOSI=1
```

### Sensor node front-end

Voltage divider feeds GPIO7. A 100nF ceramic cap between GPIO7 and GND filters ADC noise. The MCU itself is powered through a buck converter (Pololu D24V10F5 recommended — 36V max input, 5V out) tapped off the same VBAT line.

**Do NOT feed VBAT directly to the Heltec USB or VIN pin.** It will destroy the board. Buck converter is mandatory.

## Packet format

ASCII string, comma-separated:

```
T:<type>,N:<id>,V:<voltage>,S:<status>
```

Example: `T:OB,N:1,V:14.73,S:0`

- `type` — `OB` (onboard) or `BL` (block)
- `id` — 1-99, unique per physical node (hardcoded at flash time)
- `voltage` — float, 2 decimal places
- `status` — 0=OK, 1=WARN (below `WARN_V`), 2=CRIT (below `CRIT_V`)

Thresholds:
- Onboard: WARN=13.5V, CRIT=12.8V
- Block: WARN=21.0V, CRIT=20.0V

## Radio config (must match on all nodes)

```
Frequency: 915.0 MHz
Bandwidth: 125 kHz
Spreading factor: 9
Coding rate: 4/5
Sync word: 0xAB
TX power: 17 dBm
Preamble: 8
```

SF9 chosen for 50–100m range with obstacles (typical on-set use). Up to 12 nodes tracked, packets every 10s — no collision concern.

## Source files

Three Arduino sketches in this folder:

- `sensor_onboard_heltec_v3.ino` — flash to each onboard battery sensor
- `sensor_block_heltec_v3.ino` — flash to each block/floor battery sensor  
- `receiver_heltec_v3.ino` — flash to the handheld receiver

Before flashing each sensor node, change `NODE_ID` at the top of the file (1, 2, 3...). `NODE_TYPE` is fixed per file — don't change it.

## Build environment

**Arduino IDE 2.x** with ESP32 board support:

1. File → Preferences → Additional Board Manager URLs:
   `https://raw.githubusercontent.com/espressif/arduino-esp32/gh-pages/package_esp32_index.json`
2. Tools → Board → "Heltec WiFi LoRa 32(V3)"
3. Tools → USB CDC On Boot → **Enabled** (required for Serial over USB-C)
4. Tools → Upload Speed → 921600

**Libraries** (Library Manager):
- `RadioLib` by Jan Gromeš (handles SX1262)
- `GxEPD2` by ZinggJM (e-ink, receiver only)
- `Adafruit GFX Library` (dependency for GxEPD2)

## Where to start

The most useful next steps for Claude Code:

1. **Bench test sketch** — write a minimal test that just sends/receives a "ping" packet to verify the radio link works before wiring up any analog circuitry. Both ends should be Heltec V3s, no divider needed.

2. **Calibration routine** — add a one-time calibration mode to sensor nodes. User holds a button on boot, feeds a known voltage (e.g. measured with a multimeter), node stores the calibration factor in NVS/preferences. This corrects for resistor tolerance.

3. **Deep sleep** — sensor nodes currently use `delay()` between transmissions. Switch to `esp_deep_sleep_start()` for ~10µA sleep current. Wake every 10s, take reading, transmit, sleep. Massive battery life improvement.

4. **PCB design** — sensor node PCB with screw terminals for VBAT input, divider resistor footprints, decoupling cap, Heltec V3 castellated footprint or headers, buck converter footprint. Two variants or one universal board with DNP options.

5. **Receiver UX improvements:**
   - Button to cycle through pages when more than 5 nodes connect (currently truncates at row 5)
   - Buzzer or piezo for CRIT alerts
   - Battery indicator for the receiver's own LiPo
   - RSSI bars per node (data already available — see `radio.getRSSI()` in the RX handler)

6. **Persistence** — store last-seen node list in NVS so the receiver remembers which nodes existed across reboots (shows them as stale until they re-check-in).

## Known issues / open questions

- **e-ink GPIO conflict risk**: Heltec V3 has limited free pins. Confirm the e-ink pins (1, 2, 3, 4, 5, 6) don't conflict with the Heltec OLED I2C (17/18) or strapping pins (0, 45, 46). Pin 1 may be reserved on some board revisions — double check with a scope before powering up.

- **e-ink controller variant**: Code targets the `GDEY0213B74` (Waveshare V4). If a different rev arrives (`GDEH0213B72` or `GDEW0213T5D`), swap the GxEPD2 driver class in `receiver_heltec_v3.ino` line ~25.

- **AB 4-pin sourcing**: Anton Bauer 4-pin male connectors are not on Amazon. Confirmed sources: Pinknoise Systems (UK), Trew Audio (US). Alternative: buy an AB-to-D-Tap adapter cable, cut off the D-Tap end.

- **No ACK / retry**: packets are fire-and-forget. If a node misses transmission, receiver shows "stale" after 30s. For 7+ nodes this is fine; if reliability becomes an issue, add a simple ACK from receiver and retry-once on sensor side.

- **Channel sharing**: all nodes transmit on the same frequency/SF. Airtime per packet at SF9/125kHz/CR4-5 is ~200ms. With 7 nodes × 10s interval, collision probability is negligible, but verify on big shows (10+ nodes).

## Shopping references

Receiver bill of materials and sensor BOMs are documented in earlier conversation — summary:

- Heltec WiFi LoRa 32 V3 (915 MHz) — Amazon, ~$22 ea
- Waveshare 2.13" e-Paper HAT V4 — Amazon, ~$22
- D-Tap male connectors — B&H (Cable Techniques CT-DTAP-M)
- AB 4-pin connectors — Pinknoise / Trew Audio
- Pololu D24V10F5 buck converters
- 1% metal film resistors (100k, 22k, 180k, 27k)
- 100nF ceramic caps (104)

## Coding conventions used so far

- Single `.ino` per sketch, no external `.h` files yet — fine for the current size
- All config at the top of each file as `#define`s
- Magic numbers in the divider formula are calculated inline as comments (`ADC_SCALE` precomputed at compile time)
- Serial output format: `[TX]` / `[RX]` prefix, type+id, voltage, status, optional RSSI
- 2-space indent, K&R braces

Feel free to refactor into shared headers (`config.h`, `packet.h`, `lora_setup.h`) once the codebase grows past ~500 lines — that's the natural breakpoint.

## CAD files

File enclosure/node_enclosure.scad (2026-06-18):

// brickdup — sensor-node enclosure (parametric OpenSCAD)
// =================================================================
// Version: v10 (2026-06-18) — east bay bumped to bay_l 20 (~10 mm clear
//          behind the LEMO).
//          v9 (2026-06-18) — east bay deepened (bay_l 12 → 18) so the LEMO's
//          rear solder cups/wires clear the board/tray.  Because USB,
//          buttons, OLED + board are all west-referenced, only the east wall
//          (LEMO/SMA) moves — lid is unchanged; box grows ~6 mm in length.
//          v8 (2026-06-18) — LEMO back to lemo_y 14 (the v7 scoot left no
//          room for the panel nut to spin on the back).
//          v7 (2026-06-18) — SMA flat opened to 5.9; LEMO scooted toward
//          the south wall (lemo_y 14 → 12.5).
//          v6 (2026-06-18) — LEMO double-D rotated 90°: flats now on the
//          left + right of the hole (were top/bottom).
//          v5 (2026-06-11) — LEMO and SMA swapped on the east wall:
//          LEMO's rear now faces the south channel for wire access; LEMO
//          hole 8.9 mm (measured, was the 12 mm guess) with its double-D
//          flats (8.2), SMA single flat (5.75); nub-side tray wall +1.5
//          and the snap nubs raised +1.5 to match the board's ride height
//          with the battery installed; USB hole shifted 1 mm south (the
//          port isn't quite on the board centreline).
//          v4 (2026-06-11) — battery pocket opened up to the calipered
//          cell (41.39x25.15x10.25): towers slimmed to 3 mm + pushed to
//          the ribs (42 mm clear span), end stop gone, tape retention.
//          v3 (2026-06-11) — post-print fit pass on the v2 print: button
//          height corrected from fit symptom (plunger pressed the switch
//          with the lid screwed tight), plunger flange slimmed to match,
//          tray length -1.
//          v2 (2026-06-10) — first measured revision: real board/buck/
//          LEMO dims, click-in board tray, captive button plungers.
//          (v1 = the pre-measurement scaffold, git history before this.)
//
// STACKED + SIDE-CHANNEL layout:
//
//   z 2..12   1100 mAh bridge LiPo (41.4x25.15x10.25) flat on the floor
//   z 15..16  Heltec WiFi LoRa 32 V3 on four 13 mm corner towers,
//             directly above the cell (battery JST is on the board's
//             underside, so the lead run is tiny)
//   south ch  buck recess in the floor + wire raceway (tracks buck width)
//   north ch  divider / wire slack raceway (7 mm wide)
//   east bay  LEMO panel connector tail + divider
//
// The board sits ~2.5 mm from the west wall, so USB-C is a normal
// chamfered port hole (~4 mm recess), not a deep slot.  All four M2
// screws are internal corner bosses, in the channel corners.  Channels
// open into the east bay, so wires run LEMO → channel → buck → board
// without rib gaps.  Outer ≈ 76 x 54 x 24 mm.
//
// part = "both" renders base + lid + plungers in print orientation.
//
// Every value marked MEASURE is a best guess from ENCLOSURE.md — verify with
// calipers and a dry fit before the final print.  Print a fit test of the
// USB cutout + LEMO hole first (ENCLOSURE.md §7).
//
// Known scaffold compromises (check at dry fit, tune as needed):
//   - Assumes NO bottom-facing pin headers on the Heltec (Heltec ships them
//     unsoldered).  If yours are soldered pointing down, raise standoff_h
//     to ~22 and the shell grows ~9 mm taller.
//   - USB-C port face sits ~4 mm behind the outer wall.  The 12x7 chamfered
//     hole lets a plug nose seat through that on most cables — check yours;
//     enlarge usb_w/usb_h if the nose is chunky.  The lid's lip is notched
//     above the port so the plug doesn't hit it.
//   - The LEMO body is 12 mm from the back of its flange (measured), so it
//     intrudes 10 mm past the 2 mm wall — and the bay is 20 mm deep, so its
//     rear cups/wires sit ~10 mm clear of the bay rib (board edge).  At the
//     SE position its rear lines up with the south channel, so the leads
//     run straight down the channel (toward the buck) with no sharp bend.
//   - LiPo: cell measured 41.39 x 25.15 x 10.25.  It sits between the
//     corner towers (42 mm clear span, ~0.65 mm/side width-wise), tape-
//     retained — no end stop, so the leads have free run to the bay-rib
//     gap.  Never squeeze the pouch.
//   - The board CLICKS into its tray: full-height cradle walls (2 mm past
//     the PCB top), a continuous chamfered lip on the south rib, and two
//     snap nubs on flex tabs on the north rib.  Assembly: tilt the south
//     edge under the lip's 45° mouth (~1.7 mm above the board), press the
//     north edge down past the nubs — pinned at 0.3 mm.  All overhangs are
//     45°, so it prints supportless.
//   - Buttons are actuated by CAPTIVE PRINTED PLUNGERS (no exposed PCB):
//     each button gets a guide tube under the lid and a printed piston,
//     dropped in from the inside before the lid goes on.  The flared cone
//     keeps it captive; the tactile switch's own spring returns it.  Verify
//     `btn_top` (button cap height above the PCB) or the throw will be off.
//     The guide-tube length is DERIVED from the under-lid headroom; with
//     comp_h = 4 the lid sits low, so the flange stack is slimmed to fit.
//     A console warning prints if the headroom is too small for the flange.
//     Set plungers = false to fall back to plain access holes.

part = "both"; // [both, base, lid, plunger, assembly]

/* ---------------- global ---------------- */
wall   = 2.0;   // shell wall
lid_t  = 2.4;   // lid plate (screw counterbores live here)
tol    = 0.20;  // slip-fit clearance
fillet = 2.5;   // outer corner radius (XY)
rib    = 1.6;   // internal partition thickness
pad    = 2.0;   // margin between west wall and the board zone (= rim width)
$fn = 48;

/* ---------------- Heltec WiFi LoRa 32 V3 ---------------- */
pcb_l      = 47.0;  // measured, then -1 after the v2 print (tray = pcb_l + 1)
tab_gap    = 18.0;  // bay-rib gap for the board's u.FL antenna tab (+ wires),
                    // centred on the board  MEASURE tab width/offset
pcb_w      = 25.5;  // MEASURE
pcb_t      = 1.0;
comp_h     = 4.0;   // tallest part above PCB (OLED/USB)  MEASURE
standoff_h = 13.0;  // tower height: LiPo (10) + 1 air + 2 wire room underneath

/* ---------------- bridge LiPo (MakerHawk 1100 mAh) ---------------- */
lipo_l = 41.4;  lipo_w = 25.15;  lipo_t = 10.25; // measured (v2 print fit);
                                                 // length excludes the leads —
                                                 // they exit via the bay-rib gap

/* ---------------- buck (Pololu D24V10F5) ---------------- */
buck_l = 12.7;  buck_w = 12.0;   // width measured; length from datasheet 0.5"
buck_recess = 0.6;               // floor recess to locate it (foam-tape it in)
buck_x = 20.0;                   // recess position along the south channel

/* ---------------- channels & east bay ---------------- */
ch_s  = buck_w + 1.5;  // south channel: buck + wires (tracks the buck recess)
ch_n  = 7.0;    // north channel: divider / wire slack
bay_l = 20.0;   // east bay: LEMO tail (10 into cavity) + wire bend + divider.
                // Deeper than the tail needs (was 12) to keep the LEMO's rear
                // solder cups + wires well clear of the board/tray — ~10 mm of
                // open space behind the connector before the bay rib.

/* ---------------- connectors ---------------- */
usb_w = 12.0;  usb_h = 7.0;      // port hole, chamfered  MEASURE plug nose
usb_y_off = -1.0;                // port sits ~1 mm south of the board
                                 // centreline (print fit)
lemo_hole_d = 8.9;   // measured
lemo_flat = 8.2;     // measured across the LEMO's two flats (double-D hole,
                     // flats left + right since v6)
lemo_y = 14.0;       // LEMO at the SE spot (swapped with the SMA): its rear
lemo_z = 14.0;       // faces the open bay + south channel, so there's working
                     // room to solder and dress the leads.  Kept off the south
                     // wall so the panel nut has room to spin on the back.
sma_d = 6.5;         // SMA bulkhead pass-through  VERIFY (east wall)
sma_flat = 5.9;      // measured flat-to-round (single flat, on the bottom)
sma_z = 9.0;         // SMA takes the old LEMO spot: board centreline, low

/* ---------------- lid features (offsets from the PCB's SW corner) ------- */
oled_off_x = 20.0;   // MEASURE  (active area 21.7 x 11, roughly mid-board)
oled_off_y = 7.25;   // MEASURE
oled_w = 23.7;       // window = active area + ~1 mm margin per side
oled_h = 13.0;
prg_x = 4.5;   prg_y = 5.0;    // MEASURE  PRG/USER button centre
rst_x = 4.5;   rst_y = 20.5;   // MEASURE  RST button centre
btn_d = 4.5;                   // access-hole diameter (plungers = false only)
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

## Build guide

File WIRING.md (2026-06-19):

# brickdup — Sensor Node Wiring

Nodes are **powered by the very battery they monitor**, through a buck converter
— there is no separate node battery. The MCU never sees raw pack voltage; only
the buck's regulated 5V and a divided-down sense voltage.

> ⚠️ **Never** connect raw battery voltage to the Heltec USB-C port, the `5V`
> pin, or `3V3`. Raw pack voltage goes **only** to the buck `VIN` and the top of
> the divider (R1). Everything else runs off the buck's regulated 5V. Getting
> this wrong destroys the board.

---

## Universal node (recommended) — 4S **or** 6S, up to 25.2V

One divider sized for 6S that also reads 4S fine. The battery type is a firmware
setting (web page or long-press PRG) — **no extra wiring** for it.

| Item | Value |
|---|---|
| R1 (VBAT → GPIO7) | **200 kΩ** (2 × 100 kΩ in series, as built) |
| R2 (GPIO7 → GND) | **22 kΩ** (as built; 27 kΩ was the original design value) |
| GPIO7 at 25.2V (6S full) | **~2.50 V** (big headroom under the 3.3V ADC ceiling) |
| GPIO7 at 16.8V (4S / VCLX full) | ~1.66 V |
| Buck | Pololu **D24V10F5** (36V max in → 5V) — must be 36V-rated for 6S |
| Bridge LiPo | 1S, **~1100 mAh**, JST 1.25 (backup — buck keeps it charged) |

Node wiring schematic

```
                 ┌──► Buck VIN ──► VOUT 5V ──► Heltec "5V" pin ──► powers board
   VBAT ─────────┤                                              └─► charges LiPo
 (4S or 6S,      └──[200kΩ]──┬────────┬──► GPIO7                   (onboard charger)
  ≤25.2V)                    │        │
                          [22kΩ]   [100nF]            Bridge LiPo (~1100mAh, 1S)
                             │        │                  └─► Heltec JST 1.25
   GND ──────────────────────┴────────┴──► Heltec GND  +  Buck GND  +  LiPo −
```

> ⚠️ **The 100 nF cap sits ACROSS R2** (sense node → GND, i.e. in parallel —
> easiest is to solder it leg-to-leg across R2). It is **not** in series with
> the GPIO7 wire: a series cap blocks DC and the pin would read nothing.
> Three things meet at the sense node: R1's bottom leg, R2's top leg + cap,
> and the wire to GPIO7.

- **Bridge LiPo (backup):** a small 1S LiPo on the Heltec's JST connector. The
  buck **charges it** from the camera battery (via the 5V pin → onboard charger)
  and **powers the node**; the LiPo only carries the node during a battery swap
  or after the camera battery dies — so the node **stays alive to report a dead /
  removed camera battery for sure**, and never reboots on a swap. ~1100mAh is
  plenty (it's topped off whenever a camera battery is connected).
- **Buck rating matters:** for 6S (25.2V) use the 36V-rated D24V10F5. A 28V buck
  (e.g. MP1584 modules) is too marginal for 6S. The buck now also supplies the
  LiPo charge current (~500mA) on top of the board — the 1A D24V10F5 handles it.
- The universal sketch reads GPIO7 with `analogReadMilliVolts()` (factory ADC
  calibration), so the only constant is the divider ratio
  `DIVIDER_RATIO = (222/22)` = (R1+R2)/R2. If you fit different resistors,
  update that. (The legacy OB/BL sketches still use raw `analogRead` × their
  own `ADC_SCALE`.)
- After wiring, **calibrate** on the web page against a multimeter.

---

## Legacy single-mode variants

The two original sketches use fixed dividers (one per battery type). Prefer the
universal node above; these are kept for reference.

## Common to both variants

| Part | Value / Model |
|---|---|
| MCU | Heltec WiFi LoRa 32 V3 |
| Buck converter | Pololu **D24V10F5** (36V max in → 5V out) |
| Sense pin | **GPIO7** (ADC1_CH6) |
| ADC filter cap | **100 nF** (104) ceramic, GPIO7 → GND |

**Power path (identical for both):**
```
Battery + (VBAT) ──► Buck VIN
Battery − (GND)  ──► Buck GND
Buck VOUT (5V)   ──► Heltec "5V" pin
Buck GND         ──► Heltec GND
```

**Sense path (resistor values differ per variant — see below):**
```
Battery + (VBAT) ──[ R1 ]──┬──[ R2 ]── GND
                           │
                           ├──► Heltec GPIO7
                           │
                          100nF
                           │
                          GND
```

Tie **all grounds common**: battery −, buck GND, divider bottom, the cap, and
Heltec GND.

---

## Onboard variant (`OB`) — 4S Li-Ion, ≤ 16.8V

Sketch: `sensor_onboard_heltec_v3/`
Connector: D-Tap or AB 4-pin

| Item | Value |
|---|---|
| R1 (VBAT → GPIO7) | **100 kΩ** |
| R2 (GPIO7 → GND) | **22 kΩ** |
| Divider ratio | 22 / (100+22) |
| GPIO7 at 16.8V | **3.03 V** (under the 3.3V ADC ceiling) |
| WARN threshold | **13.5 V** |
| CRIT threshold | **12.8 V** |

```
                 ┌─────────────► Buck VIN ──► VOUT 5V ──► Heltec 5V
   VBAT ─────────┤
 (4S, ≤16.8V)    └──[100kΩ]──┬────────┬──► GPIO7
                             │        │
                          [22kΩ]   [100nF]
                             │        │
   GND ──────────────────────┴────────┴──► Heltec GND  +  Buck GND
```

---

## Block variant (`BL`) — 6S Li-Ion, ≤ 25.2V

Sketch: `sensor_block_heltec_v3/`
Connector: AB 4-pin (inline)

| Item | Value |
|---|---|
| R1 (VBAT → GPIO7) | **180 kΩ** |
| R2 (GPIO7 → GND) | **27 kΩ** |
| Divider ratio | 27 / (180+27) |
| GPIO7 at 25.2V | **3.29 V** (just under the 3.3V ADC ceiling) |
| WARN threshold | **21.0 V** |
| CRIT threshold | **20.0 V** |

```
                 ┌─────────────► Buck VIN ──► VOUT 5V ──► Heltec 5V
   VBAT ─────────┤
 (6S, ≤25.2V)    └──[180kΩ]──┬────────┬──► GPIO7
                             │        │
                          [27kΩ]   [100nF]
                             │        │
   GND ──────────────────────┴────────┴──► Heltec GND  +  Buck GND
```

> Note: the BL divider lands at **3.29V** near full charge — deliberately close
> to the 3.3V ADC limit for resolution. Use 1% resistors and don't exceed 25.2V
> in (a 6S pack's max). If you want more headroom, bump R1 to 200kΩ and update
> `ADC_SCALE` in the sketch.

---

## Before flashing for real use

- Set **`USB_TEST_MODE 0`** in the onboard sketch. While it's `1` the node reads
  the Heltec's *own* onboard battery sense (for bench testing over USB-C), not
  the GPIO7 divider.
- The `100nF` cap belongs **right at GPIO7 → GND** to quiet ADC noise.
- 1% resistor tolerance still leaves readings off by a few tenths of a volt until
  a calibration routine exists — trim using the resistors' measured values, or
  adjust `ADC_SCALE`, if you need it tighter now.

## Pin reference (Heltec V3, same on every board)

```
LoRa SX1262 (HSPI):  CS=8, DIO1=14, RST=12, BUSY=13 | SCK=9, MISO=11, MOSI=10
ADC sense:           GPIO7 (ADC1_CH6)
External 5V in:      "5V" pad (a.k.a. Vextin/VS on some clones — confirm silkscreen)
```

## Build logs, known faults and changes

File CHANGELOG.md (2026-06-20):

# Changelog

Firmware version shown in each unit's screen corner (`FW_VERSION`). All three
sketches share the same version number. Bump `FW_VERSION` in each `.ino` when
cutting a release and add an entry here.

> Note: early development wasn't individually versioned — the version display
> shipped as `0.1.0` and stayed there while features piled on. `0.5.0` is the
> first deliberate bump and rolls up everything below. Numbers are approximate
> by design; this is pre-hardware-validation firmware.

## 0.5.9 — current

- Editable alert thresholds in the node portal. WARN/CRIT are no longer
  hardcoded — the config page has WARN/CRIT fields for the current battery type,
  saved per type (OB and BL each keep their own) in NVS. Defaults unchanged
  (OB 13.5/12.8V, BL 21.0/20.0V); `/thresh` validates WARN > CRIT within a sane
  range. Switch battery type to edit the other type's pair.

## 0.5.8

- Clear node list now works in the captive-portal popup, not just Safari. The
  form's `onsubmit="return confirm(...)"` was the blocker: iOS's captive
  mini-browser (CNA) doesn't run `confirm()`, so it returned false and
  cancelled the submit. Dropped the confirm (clearing is low-stakes — live
  nodes just re-appear) and made handleClear's redirect an absolute URL.

## 0.5.7

- Clear-node-list reliability (receiver): the button was a JS `fetch('/clear')`,
  which the captive-portal mini-browsers (iOS/Android) often block — so on those
  it silently did nothing and dead/lost nodes never cleared. Replaced with a
  plain form submit; `handleClear` now redirects back to the dashboard. Added a
  `[CLEAR]` serial log to confirm the handler runs.

## 0.5.6

- Fix the bridge-LiPo read for real: the GPIO37 enable was reading 0 mV on LOW
  (Heltec docs notwithstanding), so the sense divider was never connected. New
  `VBAT_ON HIGH` connects it; this board reads correctly now. `LIPO_RATIO` may
  still need a small trim against a meter once it shows a real number. (The
  `[LIPO] pin=… mV` serial line is still on for verification — remove later.)

## 0.5.5

Receiver fixes (reflash the receiver only):
- "Clear node list" now redraws the e-ink immediately instead of waiting for
  the next packet, so clearing a stale/dead node actually removes it on screen.
  (A *live* node still re-appears on its next 10s transmit — that's expected.)
- Dashboard no longer shows stale full signal bars for a disconnected (LOST)
  node — bars now read 0 unless the node is FRESH/STALE, matching the e-ink.
  Note: at close bench range every node legitimately shows 3 bars (RSSI ≥ -95);
  bars only drop with real distance/obstacles.

## 0.5.4

- Fix the bridge-LiPo read (`B:` was reporting `Li 0.0V`). The onboard
  battery-sense path had never actually run before — `DEMO_VOLTAGE_ON` masked
  the only code that used it — so its 5 ms settle was too short. Now: settle
  `LIPO_SETTLE` (20 ms), read in mV via `analogReadMilliVolts()`, scale by the
  V3 onboard divider ratio `LIPO_RATIO` (~4.9, trim against a meter).

## 0.5.3

Bridge-LiPo support / explicit dead-battery reporting:
- Node reads its bridge LiPo (Heltec onboard sense) and broadcasts it as a new
  `B:<volts>` packet field, plus a new status `S:3` ("no source") when the
  camera battery reads below `SOURCE_MIN_V` (5V). Instead of going silent when
  the camera battery is pulled/dies, the node stays alive on the LiPo and says
  so. Node OLED shows `NO BATT` + the bridge level in that state.
- Receiver parses `B:`/`S:3`, shows an **explicit DEAD** (steady inverted bar)
  for a node reporting no source — distinct from the old *inferred* DEAD
  (silent-after-CRIT), which still works. DEAD rows show the node's `Li x.xV`
  in place of a meaningless SoC; SoC/rate aren't updated from a no-source
  packet. Dashboard JSON gains `lipo`; table shows DEAD + Li level.
- Packet is forward/backward compatible (prefix-matched fields, unknowns
  ignored).

## 0.5.2

- Universal node: read GPIO7 with `analogReadMilliVolts()` (ESP32-S3 factory
  ADC calibration) instead of raw `analogRead()` × an assumed 3.3/4095. Much
  better absolute accuracy and low-end behaviour; the only scale left is the
  divider ratio (`DIVIDER_RATIO` = 222/22). Fixes the ~0.2V high reading that
  single-point calibration couldn't remove. Recalibrate (reset, then set) after
  flashing.
- Other sketches: version bump only (shared `FW_VERSION`).

## 0.5.1

- Universal node: `ADC_SCALE` set to the as-built divider — R1 = 200kΩ
  (2×100kΩ in series), R2 = **22kΩ** (was the 27kΩ design value). 25.2V now
  reads ~2.5V on GPIO7; recalibrate via the portal after flashing.
- Other sketches: version bump only (shared `FW_VERSION`).

## 0.5.0

Everything since the initial build, gathered into one version:

**Sensor nodes**
- Per-node OLED readout (WiFi name, status, user name, big voltage, version)
- WiFi config portal: rename, single-point voltage calibration (saved to flash)
- Chip-serial permanent id (`OB-7F3A`) = WiFi network name; flash identical
  firmware to every node, configure over WiFi (no per-unit edits)
- WiFi toggle on the PRG button; on/off state persists across reboots
- Name length capped at 10 chars
- Embedded brickdup logo on the config page
- OTA firmware update (`/update`)
- Triple-tap power off (deep sleep), press to wake; "POWERED DOWN" screen
- USB-C bench-test mode (`USB_TEST_MODE`)

**Receiver**
- e-ink dashboard: per-node name, voltage, SoC % + rough time-to-empty,
  3-bar RSSI, and OK / WARN / CRIT / STALE / DEAD / LOST states
- DEAD vs LOST inference (silent-after-CRIT = dead battery; LOST flashes)
- USER button: short = page, long = web dashboard, triple-tap = power off
- Live web dashboard (full node table on your phone) + "Clear node list"
- Node roster persists across reboots (NVS)
- Receiver's own battery on the header, with "+" while charging
  (rising-trend; optional `VBUS_PIN` for definitive USB detection)
- One-decimal voltages; tiny firmware-version corner
- OTA firmware update (`/update`)

**Packet format** `T:<type>,I:<permId>,V:<voltage>,S:<status>[,M:<name>]`

## 0.1.0 — initial versioned build

- Base sensor-node + receiver firmware, OLED / e-ink output, LoRa link,
  early WiFi naming portal. (Version display added here.)

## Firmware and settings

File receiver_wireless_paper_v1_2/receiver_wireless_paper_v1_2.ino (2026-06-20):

// Brickdup — Handheld receiver
// Hardware: Heltec Wireless Paper (ESP32-S3 + SX1262 + built-in 2.13" e-ink)
//
// Board version: V1.2 (confirmed from PCB silkscreen).
// If you ever swap boards: V1.0 → EInkDisplay_WirelessPaperV1,
// V1.1 → EInkDisplay_WirelessPaperV1_1, V1.1.1 → EInkDisplay_WirelessPaperV1_1_1
//
// Libraries needed (Library Manager):
//   - RadioLib by Jan Gromeš
//   - heltec-eink-modules by todd-herbert  ← replaces GxEPD2

#include <RadioLib.h>
#include <heltec-eink-modules.h>
#include <WiFi.h>
#include <WebServer.h>
#include <DNSServer.h>       // captive portal (dashboard auto-pops on connect)
#include <Preferences.h>
#include <Update.h>          // built-in OTA (web firmware update)
#include <esp_sleep.h>       // deep sleep (triple-tap power off)
#include <Fonts/FreeSansBold12pt7b.h>
#include <Fonts/FreeSansBold9pt7b.h>
#include <Fonts/FreeSans9pt7b.h>
#include <Fonts/TomThumb.h>          // tiny 3x5 font for the version corner

#define FW_VERSION "0.5.9"

// ── LoRa pins (same as Heltec V3) ────────────────────────────────────────────
#define LORA_CS    8
#define LORA_DIO1  14
#define LORA_RST   12
#define LORA_BUSY  13
// HSPI: SCK=9, MISO=11, MOSI=10

// ── E-ink pins (internal wiring on Wireless Paper, for reference only) ───────
// RST=6, DC=5, CS=4, BUSY=7, SCK=3, MOSI=2 — handled by library, do not redefine

// ── Controls ──────────────────────────────────────────────────────────────────
#define BTN_PIN      0          // Wireless Paper onboard USER button (GPIO0)
#define LONGPRESS_MS 1200       // hold this long to toggle the web dashboard

// ── Web dashboard ─────────────────────────────────────────────────────────────
#define AP_PASSWORD  "brickdup" // password for the receiver's WiFi network

// ── Receiver's own battery sense (Wireless Paper) ─────────────────────────────
// From the Meshtastic variant: ADC_CTRL=19 (enable LOW), VBAT on GPIO20 (ADC2),
// divider is ~1:2 so multiply the pin voltage by 2. ADC2 is OK — no WiFi here.
#define VBAT_CTRL     19
#define VBAT_ADC      20
#define VBAT_MULT     2.0f
#define BATT_SAMPLE_MS 15000UL   // sample every 15s (so "+" clears promptly)

// Optional definitive USB detection. Wire the board's 5V/VBUS pin through a
// divider (e.g. 100k/220k → ~3.3V) to a spare GPIO and set VBUS_PIN to it; the
// pin reads HIGH whenever USB is plugged in. Leave at -1 to use the voltage
// trend instead (which only catches an actively-rising charge).
#define VBUS_PIN      -1

// ── DEMO: populate fake nodes to preview the display. Set to 0 for normal use.
#define DEMO_NODES    0

// ── Radio config (must match all nodes) ──────────────────────────────────────
#define FREQ_MHZ   915.0
#define BW_KHZ     125.0
#define SF         9
#define CR         5       // 4/5
#define SYNC_WORD  0xAB
#define TX_PWR     17
#define PREAMBLE   8

// ── Node tracking ─────────────────────────────────────────────────────────────
// Nodes transmit every ~10s. Tiers are timed to ride out a single dropped
// packet (a ~20s gap) without false alarms, but flag a real loss quickly:
#define MAX_NODES    12
#define STALE_MS     15000UL   // ~1-2 missed → STALE (last reading shown, flagged)
#define LOST_MS      28000UL   // ~3 missed   → LOST  (signal gone)
#define STATUS_NOSRC 3         // node S: value = camera battery removed/dead
                               // (node stays alive on its bridge LiPo to report it)
#define CHECK_MS     1000UL    // re-evaluate freshness every 1s for a prompt redraw
#define DISPLAY_ROWS 5

// Freshness tiers
enum Tier { FRESH = 0, STALE = 1, LOST = 2 };

struct NodeState {
  char     permId[16];  // permanent unique id from the node, e.g. "OB-7F3A" (key)
  char     type[4];     // "OB" or "BL"
  char     name[20];    // friendly name broadcast by the node (empty if none)
  float    voltage;
  uint8_t  status;      // 0=OK  1=WARN  2=CRIT  3=NO SOURCE (battery removed/dead)
  float    lipo;        // node's bridge LiPo volts (B: field; 0 if not reported)
  int16_t  rssi;
  uint32_t lastSeen;
  bool     active;
  // Fuel-gauge estimate (computed on the receiver)
  float    soc;         // state of charge %, 100=full … 0=CRIT (practical dead)
  float    socRate;     // %/min, smoothed; negative = depleting (0 = unknown)
  float    socAtCalc;   // soc at the last rate calculation
  uint32_t lastRateMs;  // when the rate was last recomputed
};

// ── Battery fuel gauge ────────────────────────────────────────────────────────
// Per-cell Li-ion discharge curve (volts → raw % of cell charge). Roughly S-
// shaped: most of the charge lives in the upper voltages, then a knee.
struct VP { float v; float p; };
const VP CELL_CURVE[] = {
  {3.00, 0}, {3.30, 5}, {3.45, 10}, {3.58, 20}, {3.68, 30}, {3.74, 40},
  {3.79, 50}, {3.86, 60}, {3.92, 70}, {4.00, 80}, {4.10, 90}, {4.20, 100},
};
const int CELL_CURVE_N = sizeof(CELL_CURVE) / sizeof(CELL_CURVE[0]);

int   cellsFor(const char* t) { return strcmp(t, "BL") == 0 ? 6 : 4; }
float fullFor (const char* t) { return strcmp(t, "BL") == 0 ? 25.2f : 16.8f; }
float critFor (const char* t) { return strcmp(t, "BL") == 0 ? 20.0f : 12.8f; }

float rawCellSoc(float vcell) {
  if (vcell <= CELL_CURVE[0].v)             return CELL_CURVE[0].p;
  if (vcell >= CELL_CURVE[CELL_CURVE_N-1].v) return CELL_CURVE[CELL_CURVE_N-1].p;
  for (int i = 1; i < CELL_CURVE_N; i++) {
    if (vcell < CELL_CURVE[i].v) {
      float f = (vcell - CELL_CURVE[i-1].v) / (CELL_CURVE[i].v - CELL_CURVE[i-1].v);
      return CELL_CURVE[i-1].p + f * (CELL_CURVE[i].p - CELL_CURVE[i-1].p);
    }
  }
  return 100;
}

// Pack voltage → usable %, rescaled so 100% = full and 0% = CRIT (the swap point).
float socFor(const char* type, float packV) {
  int cells   = cellsFor(type);
  float raw   = rawCellSoc(packV / cells);
  float rawC  = rawCellSoc(critFor(type) / cells);
  float rawF  = rawCellSoc(fullFor(type) / cells);
  float pct   = (raw - rawC) / (rawF - rawC) * 100.0f;
  return pct < 0 ? 0 : pct > 100 ? 100 : pct;
}

// Rough minutes until 0% (CRIT / swap point), or -1 if not clearly depleting.
int etaMinutes(const NodeState& n) {
  if (n.socRate < -0.02f) return (int)(n.soc / (-n.socRate));
  return -1;
}

// Signal strength → 0..3 bars (SX1262 @ SF9 is usable down to roughly -120 dBm).
int signalLevel(int16_t rssi) {
  if (rssi >= -95)  return 3;
  if (rssi >= -110) return 2;
  if (rssi >= -120) return 1;
  return 0;
}

NodeState nodes[MAX_NODES];
int nodeCount = 0;

SX1262 radio = new Module(LORA_CS, LORA_DIO1, LORA_RST, LORA_BUSY);

// Set by the DIO1 ISR when a packet lands; loop() drains it.
volatile bool packetFlag = false;
void IRAM_ATTR onPacket() { packetFlag = true; }

// Tracks what's currently on the e-ink so we only refresh on real change.
uint32_t lastSig    = 0xFFFFFFFF;
uint32_t lastCheck  = 0;

// LOST rows flash by inverting every ~500ms (uses the panel's fast refresh mode).
#define FLASH_MS  500
bool     flashState = false;   // current flash phase
bool     flashing   = false;   // are we in fast-refresh flashing mode?
uint32_t lastFlash  = 0;

// Receiver's own battery
float    battVoltage  = 0;     // last reading (volts)
float    battEMA      = 0;     // slow average, for charging-trend detection
bool     battCharging = false; // inferred from a rising trend
uint32_t lastBatt     = 0;

// Paging + button state (short = page, long = dashboard, triple-tap = off)
int      page         = 0;
bool     btnDown      = false;
uint32_t btnPressedAt = 0;
bool     btnLongFired = false;
uint8_t  tapCount     = 0;
uint32_t lastTapMs    = 0;

// Web dashboard
Preferences prefs;
WebServer   server(80);
DNSServer   dnsServer;            // wildcard DNS for the captive portal
bool        portalActive = false;
String      apSsid;

// Node-roster persistence (remember nodes across receiver reboots)
#define  ROSTER_SAVE_MS 120000UL   // flush to NVS at most this often
bool     rosterDirty    = false;
uint32_t lastRosterSave = 0;

// Display — Wireless Paper V1.2
// Library powers GPIO45 automatically; landscape() sets 250×122 orientation
EInkDisplay_WirelessPaperV1_2 display;

// ─────────────────────────────────────────────────────────────────────────────

// ── Roster persistence ────────────────────────────────────────────────────────
// Serialize the node list to NVS as tab/newline-delimited records so the receiver
// remembers which nodes exist across a reboot (shown stale until they re-check-in).
void saveRoster() {
  String blob;
  for (int i = 0; i < nodeCount; i++) {
    NodeState& n = nodes[i];
    blob += n.permId; blob += '\t';
    blob += n.type;   blob += '\t';
    blob += n.name;   blob += '\t';
    blob += String(n.voltage, 2); blob += '\t';
    blob += String(n.status);     blob += '\n';
  }
  prefs.putString("roster", blob);
}

void loadRoster() {
  String blob = prefs.getString("roster", "");
  int start = 0;
  while (start < (int)blob.length() && nodeCount < MAX_NODES) {
    int nl = blob.indexOf('\n', start);
    if (nl < 0) break;
    String line = blob.substring(start, nl);
    start = nl + 1;
    int a = line.indexOf('\t');
    int b = line.indexOf('\t', a + 1);
    int c = line.indexOf('\t', b + 1);
    int d = line.indexOf('\t', c + 1);
    if (a < 0 || b < 0 || c < 0 || d < 0) continue;
    int idx = nodeCount++;
    nodes[idx] = {};
    strncpy(nodes[idx].permId, line.substring(0, a).c_str(),     sizeof(nodes[idx].permId) - 1);
    strncpy(nodes[idx].type,   line.substring(a + 1, b).c_str(), sizeof(nodes[idx].type) - 1);
    strncpy(nodes[idx].name,   line.substring(b + 1, c).c_str(), sizeof(nodes[idx].name) - 1);
    nodes[idx].voltage  = line.substring(c + 1, d).toFloat();
    nodes[idx].status   = line.substring(d + 1).toInt();
    nodes[idx].soc      = socFor(nodes[idx].type, nodes[idx].voltage);
    nodes[idx].active   = true;
    nodes[idx].lastSeen = millis() - STALE_MS - 1000;  // start STALE, grace to re-check-in
  }
}

#if DEMO_NODES
// Fill the table with 5 fake nodes spanning OK / WARN / CRIT for a preview.
void seedDemoNodes() {
  struct Demo { const char* id; const char* type; const char* name;
                float v; uint8_t st; int16_t rssi; float soc; float rate; };
  static const Demo d[5] = {
    {"OB-A001","OB","Cam A",   14.8f, 0,  -68, 92, -0.6f},
    {"OB-B002","OB","B-Cam",   15.1f, 0,  -82, 78, -0.9f},
    {"BL-C003","BL","Floor 1", 21.4f, 1,  -98, 40, -1.4f},
    {"OB-D004","OB","Drone",   12.9f, 2, -112,  9, -2.5f},
    {"OB-E005","OB","Steadi",  14.2f, 0, -105, 64, -0.7f},
  };
  for (int i = 0; i < 5; i++) {
    nodes[i] = {};
    strncpy(nodes[i].permId, d[i].id,   sizeof(nodes[i].permId) - 1);
    strncpy(nodes[i].type,   d[i].type, sizeof(nodes[i].type) - 1);
    strncpy(nodes[i].name,   d[i].name, sizeof(nodes[i].name) - 1);
    nodes[i].voltage  = d[i].v;
    nodes[i].status   = d[i].st;
    nodes[i].rssi     = d[i].rssi;
    nodes[i].soc      = d[i].soc;
    nodes[i].socRate  = d[i].rate;
    nodes[i].active   = true;
    nodes[i].lastSeen = millis();
  }
  nodeCount = 5;
}
#endif

int findOrCreateNode(const char* permId, const char* type) {
  for (int i = 0; i < nodeCount; i++) {
    if (strcmp(nodes[i].permId, permId) == 0) return i;
  }
  if (nodeCount < MAX_NODES) {
    int idx = nodeCount++;
    nodes[idx] = {};
    strncpy(nodes[idx].permId, permId, sizeof(nodes[idx].permId) - 1);
    strncpy(nodes[idx].type, type, sizeof(nodes[idx].type) - 1);
    nodes[idx].active = true;
    return idx;
  }
  return -1;
}

bool parsePacket(const char* buf, char* type, char* permId, size_t permLen,
                 float* voltage, uint8_t* status, float* lipo,
                 char* name, size_t nameLen) {
  // Format: T:<type>,I:<permId>,V:<voltage>,S:<status>[,B:<lipo>][,M:<name>]
  // Fields are matched by prefix, so order doesn't matter and unknown fields
  // (from older/newer firmware) are simply ignored.
  char tmp[128];
  strncpy(tmp, buf, sizeof(tmp) - 1);
  permId[0] = '\0';
  name[0]   = '\0';
  *lipo     = 0;

  char* p = strtok(tmp, ",");
  while (p) {
    if (strncmp(p, "T:", 2) == 0) strncpy(type, p + 2, 3);
    else if (strncmp(p, "I:", 2) == 0) strncpy(permId, p + 2, permLen - 1);
    else if (strncmp(p, "V:", 2) == 0) *voltage = atof(p + 2);
    else if (strncmp(p, "S:", 2) == 0) *status  = atoi(p + 2);
    else if (strncmp(p, "B:", 2) == 0) *lipo    = atof(p + 2);
    else if (strncmp(p, "M:", 2) == 0) strncpy(name, p + 2, nameLen - 1);
    p = strtok(nullptr, ",");
  }
  return (permId[0] != '\0');
}

const char* friendlyName(const NodeState& n) {
  // The node's own friendly name, or its permanent id if it hasn't been named.
  return n.name[0] ? n.name : n.permId;
}

// Read the receiver's own LiPo voltage (enable divider via ADC_CTRL, then ADC2).
float readReceiverBattery() {
  pinMode(VBAT_CTRL, OUTPUT);
  digitalWrite(VBAT_CTRL, LOW);          // enable the battery divider
  delay(5);
  uint32_t mv = 0;
  for (int i = 0; i < 8; i++) { mv += analogReadMilliVolts(VBAT_ADC); delay(2); }
  pinMode(VBAT_CTRL, INPUT);             // release (high-Z) to save power
  return (mv / 8.0f) * VBAT_MULT / 1000.0f;
}

// Sample periodically; infer "charging" from a rising trend vs the slow average.
void updateBattery() {
  // The battery is on GPIO20 = ADC2, which can't be read reliably while WiFi is
  // up (ADC2 is shared with the radio on ESP32-S3). Hold the last good value
  // while the dashboard is active; the battery moves slowly so this is fine.
  if (portalActive) return;

#if VBUS_PIN >= 0
  // Definitive: a divider off VBUS reads HIGH whenever USB is plugged in.
  // This is a plain GPIO, so it works even while WiFi is up.
  battCharging = (digitalRead(VBUS_PIN) == HIGH);
#endif

  // The battery ADC (GPIO20 = ADC2) can't be read reliably while WiFi is up.
  if (portalActive) return;
  battVoltage = readReceiverBattery();
  if (battEMA == 0) battEMA = battVoltage;        // seed
#if VBUS_PIN < 0
  // No VBUS pin wired: "+" only while the cell is actually rising. No absolute-
  // voltage clause, because a full battery reads ~4.2V whether on the charger or
  // just unplugged — so the only honest signal is whether it's climbing.
  battCharging = (battVoltage > battEMA + 0.012f);
#endif
  battEMA = battEMA * 0.8f + battVoltage * 0.2f;
}

Tier tierOf(const NodeState& n) {
  uint32_t age = millis() - n.lastSeen;
  if (age > LOST_MS)  return LOST;
  if (age > STALE_MS) return STALE;
  return FRESH;
}

// Compact signature of everything visible. If it hasn't changed, the e-ink
// doesn't need a (slow, panel-wearing) refresh.
uint32_t displaySignature() {
  uint32_t sig = 2166136261u;             // FNV-1a basis
  sig = (sig ^ (uint32_t)nodeCount) * 16777619u;
  for (int i = 0; i < nodeCount; i++) {
    NodeState& n = nodes[i];
    Tier t = tierOf(n);
    for (const char* c = n.permId; *c; c++) sig = (sig ^ (uint8_t)*c) * 16777619u;
    for (const char* c = n.name;   *c; c++) sig = (sig ^ (uint8_t)*c) * 16777619u;
    sig = (sig ^ (uint32_t)t) * 16777619u;
    sig = (sig ^ n.status) * 16777619u;   // also distinguishes LOST vs DEAD
    sig = (sig ^ (uint32_t)(n.lipo * 10)) * 16777619u;  // bridge-Li readout (DEAD rows)
    if (t == FRESH) {
      sig = (sig ^ (uint32_t)(n.voltage * 10)) * 16777619u;  // 0.1V = displayed res
      sig = (sig ^ (uint32_t)(n.soc / 5)) * 16777619u;       // 5% buckets
      int eta = etaMinutes(n);                               // 10-min buckets
      sig = (sig ^ (uint32_t)((eta < 0 ? 9999 : eta) / 10 + 1)) * 16777619u;
      sig = (sig ^ (uint32_t)signalLevel(n.rssi)) * 16777619u;
    }
  }
  // Receiver battery (0.1V resolution) + charging flag, so the header refreshes
  // only when the displayed value actually changes.
  sig = (sig ^ (uint32_t)(battVoltage * 10)) * 16777619u;
  sig = (sig ^ (uint32_t)battCharging) * 16777619u;
  sig = (sig ^ (uint32_t)page) * 16777619u;          // redraw when the page changes
  sig = (sig ^ (uint32_t)portalActive) * 16777619u;  // show/hide WiFi indicator
  return sig;
}

// Three signal bars of increasing height; filled = active, outline = empty.
void drawBars(int x, int baseY, int level, uint16_t color) {
  const int bw = 3, gap = 2, h[3] = {4, 8, 12};
  for (int i = 0; i < 3; i++) {
    int bx = x + i * (bw + gap);
    int by = baseY - h[i] + 1;
    if (i < level) display.fillRect(bx, by, bw, h[i], color);
    else           display.drawRect(bx, by, bw, h[i], color);
  }
}
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
void loop() {
  pollButton();                              // short=page, long=toggle dashboard
  if (portalActive) { dnsServer.processNextRequest(); server.handleClient(); }

  // 1. Drain any received packet
  if (packetFlag) {
    packetFlag = false;
    handlePacket();
    maybeRefresh();       // show new data promptly
  }

  // Sample the receiver's own battery now and then
  if (millis() - lastBatt > BATT_SAMPLE_MS) {
    lastBatt = millis();
    updateBattery();
  }

#if DEMO_NODES
  // Keep the fake nodes fresh so the preview doesn't age into STALE/LOST
  for (int i = 0; i < nodeCount; i++) nodes[i].lastSeen = millis();
#else
  // Flush the roster to NVS occasionally (throttled to limit flash wear)
  if (rosterDirty && millis() - lastRosterSave > ROSTER_SAVE_MS) {
    lastRosterSave = millis();
    rosterDirty = false;
    saveRoster();
  }
#endif

  // 2. Any node in a *true* LOST state (gone silent while still healthy)?
  // Those rows flash. A DEAD node (silent after CRIT) renders steady instead.
  bool anyLost = false;
  for (int i = 0; i < nodeCount; i++) {
    if (tierOf(nodes[i]) == LOST && nodes[i].status != 2) { anyLost = true; break; }
  }

  if (anyLost) {
    // Flash the LOST row(s) by inverting every FLASH_MS, using fast refresh.
    if (!flashing) { flashing = true; display.fastmodeOn(); }
    if (millis() - lastFlash >= FLASH_MS) {
      lastFlash  = millis();
      flashState = !flashState;
      updateDisplay();
    }
  } else {
    // Nothing lost — leave fast mode and return to change-only full refreshes.
    if (flashing) {
      flashing   = false;
      flashState = false;
      display.fastmodeOff();
      lastSig = 0xFFFFFFFF;     // force one clean redraw
    }
    if (millis() - lastCheck > CHECK_MS) {
      lastCheck = millis();
      maybeRefresh();
    }
  }
}

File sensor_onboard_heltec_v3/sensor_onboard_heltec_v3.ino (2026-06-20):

// Brickdup — Onboard battery sensor node (4S Li-Ion, up to 16.8V)
// Flash the SAME firmware to every onboard node — each self-assigns a unique
// permanent id from its chip MAC, and you name it over WiFi. No per-unit edits.
// Hardware: Heltec WiFi LoRa 32 V3 (ESP32-S3 + SX1262, 915 MHz)
// Voltage divider: R1=100kΩ, R2=22kΩ on GPIO7

#include <RadioLib.h>
#include "HT_SSD1306Wire.h"   // bundled with the Heltec ESP32 board package
#include <WiFi.h>
#include <WebServer.h>
#include <DNSServer.h>        // captive portal (page auto-pops on connect)
#include <Preferences.h>
#include <Update.h>           // built-in OTA (web firmware update)
#include <esp_sleep.h>        // deep sleep (triple-tap power off)
#include "brickdup_logo.h"    // embedded logo served from /logo.jpg

// ── Identity ─────────────────────────────────────────────────────────────────
// Two names per node:
//   • PERMANENT id  — derived from the chip's unique MAC at boot, e.g. "OB-7F3A".
//     Never changes, guaranteed unique, and is the WiFi network name. This means
//     you flash the SAME firmware to every node — no per-unit edits, ever.
//   • USER name     — friendly label you assign over WiFi ("Cam A"). Defaults to
//     the permanent id until you set one. Shown on screens + broadcast.
#define NODE_TYPE  "OB"    // fixed by hardware (which divider is fitted)
#define FW_VERSION "0.5.9" // shown small in the OLED corner

// ── WiFi config portal ────────────────────────────────────────────────────────
#define AP_PASSWORD      "brickdup" // password for the node's WiFi network
#define NAME_MAXLEN      10
// WiFi draws ~80mA, so it can be toggled off to save power — no extra hardware:
//   • Tap the onboard PRG button (GPIO0) any time to toggle WiFi on/off.
//   • Or hit "Turn off WiFi" on the config page when you're done naming.
// The on/off choice is remembered across reboots — a node switched off stays
// off after a power cycle. WIFI_ON_AT_BOOT is only the first-ever-boot default.
#define WIFI_ON_AT_BOOT  1
#define PRG_BUTTON       0          // Heltec V3 onboard USER/PRG button (GPIO0)

// ── TEMPORARY: USB-C bench-test mode ──────────────────────────────────────────
// 1 = transmit the Heltec V3's onboard battery/supply voltage (~4V on USB-C)
//     instead of the external 4S divider. Lets you verify TX → RX → e-ink with
//     NOTHING wired up — just power both V3 boards over USB-C.
// 0 = real mode: read the external divider on GPIO7 for 4S monitoring.
#define USB_TEST_MODE  1

// ── Thresholds (volts) ────────────────────────────────────────────────────────
#if USB_TEST_MODE
  // Single-cell levels so a healthy USB/charge reading shows OK, not CRIT
  #define WARN_V  3.50f
  #define CRIT_V  3.30f
#else
  #define WARN_V  13.5f
  #define CRIT_V  12.8f
#endif

// ── ADC ──────────────────────────────────────────────────────────────────────
#define VBAT_PIN    7       // external 4S divider input (real mode)
#define ADC_SAMPLES 16
// Divider: Vout = Vin * R2/(R1+R2) = Vin * 22/(100+22)
// ADC_SCALE = (R1+R2)/R2 * (3.3/4095)
#define ADC_SCALE  (122.0f / 22.0f * 3.3f / 4095.0f)

// Heltec V3 onboard battery sense (test mode only)
#define VBAT_CTRL   37      // drive LOW to connect the onboard divider
#define VBAT_ADC    1       // onboard battery ADC pin
#define VBAT_CAL    0.0041f // nominal V3 divider factor (calibrate later)

// ── OLED (Heltec V3 onboard 128×64, I2C) ──────────────────────────────────────
// These macros are defined by the Heltec V3 board variant; fall back if not.
#ifndef SDA_OLED
  #define SDA_OLED 17
#endif
#ifndef SCL_OLED
  #define SCL_OLED 18
#endif
#ifndef RST_OLED
  #define RST_OLED 21
#endif
#define VEXT_PIN 36          // powers the OLED rail; LOW = on

// ── LoRa pins (Heltec V3 HSPI) ───────────────────────────────────────────────
#define LORA_CS    8
#define LORA_DIO1  14
#define LORA_RST   12
#define LORA_BUSY  13

// ── Radio config ─────────────────────────────────────────────────────────────
#define FREQ_MHZ   915.0
#define BW_KHZ     125.0
#define SF         9
#define CR         5       // 4/5
#define SYNC_WORD  0xAB
#define TX_PWR     17
#define PREAMBLE   8

// ── Timing ───────────────────────────────────────────────────────────────────
#define TX_INTERVAL_MS  10000UL

SX1262 radio = new Module(LORA_CS, LORA_DIO1, LORA_RST, LORA_BUSY);

SSD1306Wire oled(0x3c, 500000, SDA_OLED, SCL_OLED, GEOMETRY_128_64, RST_OLED);

// ── Runtime config ────────────────────────────────────────────────────────────
Preferences prefs;
WebServer   server(80);
DNSServer   dnsServer;              // wildcard DNS for the captive portal
String      g_permId;               // permanent unique id from chip MAC (SSID)
String      g_name;                 // editable user name (shown + broadcast)
float       g_cal   = 1.0f;         // calibration gain factor (1.0 = uncalibrated)
bool        portalActive = false;   // is the WiFi portal running?
bool        pendingWifiOff = false; // request to drop WiFi after a web response
bool        lastBtn = HIGH;         // PRG button edge tracking
uint32_t    lastBtnMs = 0;
uint8_t     tapCount = 0;           // triple-tap power-off
uint32_t    lastTapMs = 0;
uint32_t    lastTx = 0;

// Build the permanent id from the chip's MAC: e.g. "OB-7F3A". Unique per board.
String makePermId() {
  uint16_t suffix = (uint16_t)(ESP.getEfuseMac() & 0xFFFF);
  char buf[16];
  snprintf(buf, sizeof(buf), "%s-%04X", NODE_TYPE, suffix);
  return String(buf);
}

void drawOLED(float voltage, int status) {
  const char* tag = (status == 2) ? "CRIT" : (status == 1) ? "WARN" : "OK";
  char volt[12];
  snprintf(volt, sizeof(volt), "%.1fV", voltage);   // e.g. "14.7V"

  oled.clear();

  // Top line: WiFi network name on the left (so you can always find it),
  // status tag on the right.
  oled.setFont(ArialMT_Plain_10);
  oled.setTextAlignment(TEXT_ALIGN_LEFT);
  if (portalActive) {
    String w = "Brickdup-" + g_permId;
    oled.drawString(0, 0, w.c_str());
  } else {
    oled.drawString(0, 0, g_permId.c_str());   // WiFi off: just the device id
  }
  oled.setTextAlignment(TEXT_ALIGN_RIGHT);
  oled.drawString(128, 0, tag);
  oled.setTextAlignment(TEXT_ALIGN_LEFT);

  // User name, then the big voltage readout
  oled.setFont(ArialMT_Plain_16);
  oled.drawString(0, 14, g_name.c_str());
  oled.setFont(ArialMT_Plain_24);
  oled.drawString(0, 34, volt);

#if USB_TEST_MODE
  oled.setFont(ArialMT_Plain_10);
  oled.setTextAlignment(TEXT_ALIGN_RIGHT);
  oled.drawString(128, 40, "USB TEST");
  oled.setTextAlignment(TEXT_ALIGN_LEFT);
#endif
  // Firmware version, tiny in the bottom-right corner
  oled.setFont(ArialMT_Plain_10);
  oled.setTextAlignment(TEXT_ALIGN_RIGHT);
  oled.drawString(128, 53, "v" FW_VERSION);
  oled.setTextAlignment(TEXT_ALIGN_LEFT);
  oled.display();
}

// ── Web config portal ─────────────────────────────────────────────────────────
float readVoltage();   // fwd decl (htmlPage shows the live reading)
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

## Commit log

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2026-06-04 Add temporary USB-C test mode to onboard sensor
    USB_TEST_MODE reads the Heltec V3's onboard battery/supply sense
    (GPIO1 via GPIO37) instead of the external 4S divider, so the full
    TX -> RX -> e-ink chain can be validated over USB-C with nothing wired.
    Uses single-cell thresholds in test mode. Set USB_TEST_MODE 0 to revert.
    [sensor_onboard_heltec_v3.ino]
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2026-06-04 Fix receiver build: drawLine instead of drawFastHLine
    heltec-eink-modules' display class doesn't provide the drawFastHLine
    convenience method. Use drawLine for the header underline.
    [receiver_wireless_paper_v1_2.ino]
2026-06-04 Receiver: surface signal loss with STALE/LOST tiers
    Previously the e-ink only redrew when a packet arrived, so a node going
    silent left a stale reading frozen on screen forever. Now:
    - Interrupt-driven RX (DIO1) frees the loop to run a periodic freshness check
    - Two timeout tiers: STALE after ~30s (last reading kept, flagged),
    LOST after ~60s (shows "*** LOST ***")
    - Change-detecting refresh: e-ink only updates when the visible state
    actually changes, avoiding needless slow refreshes / panel wear
    [receiver_wireless_paper_v1_2.ino]
2026-06-04 Receiver: prominent per-node voltage readout
    Each row now shows the voltage as a large bold right-aligned number
    (FreeSansBold12pt) with the node label on the left. OK/WARN/CRIT is
    shown by the left marker box instead of a text tag. STALE keeps the
    last value with a small "stale" flag; LOST replaces it with the word.
    [receiver_wireless_paper_v1_2.ino]
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2026-06-04 Receiver: friendly node names + bold CRIT/LOST rows
    - Editable NODE_NAMES table maps type+id to readable labels (e.g. OB-1 ->
    "Cam A"); unlisted nodes fall back to their raw tag.
    - CRIT and LOST rows now render as an inverted black bar with white text
    so they stand out across a room; WARN keeps the outline marker.
    - "stale" flag repositioned to follow the (variable-width) node name.
    [receiver_wireless_paper_v1_2.ino]
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2026-06-04 Chip-derived permanent id: zero per-unit config
    Replaces the numeric NODE_ID model with a permanent id auto-derived from
    each chip's MAC (e.g. "OB-7F3A"). Guaranteed unique, never changes, and is
    the WiFi network name — so identical firmware flashes to every node with no
    edits. The user-assignable name is now purely a friendly label that defaults
    to the permanent id.
    - Nodes: permId from ESP.getEfuseMac(); user name defaults to it; packet uses
    I:<permId> instead of N:<id>; web form drops the id field
    - WiFi portal gating scaffolded behind WIFI_ALWAYS_ON / PRG button at boot
    - Receiver keys nodes on permId; friendlyName = name or permId; NODE_NAMES
    table removed
    - README + packet forma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
    [receiver_wireless_paper_v1_2.ino, sensor_block_heltec_v3.ino, sensor_onboard_heltec_v3.ino]
2026-06-04 Show WiFi name on OLED; make permanent name read-only text
    - OLED top line now shows the WiFi network name (Brickdup-OB-7F3A) so you can
    still find which AP to join after assigning a friendly name; status tag moves
    to the top-right.
    - Web page shows the permanent WiFi name as a styled read-only block instead of
    a disabled input field, so it no longer looks editable.
    [sensor_block_heltec_v3.ino, sensor_onboard_heltec_v3.ino]
2026-06-04 WiFi on/off toggle with no added hardware
    Uses the Heltec V3's onboard PRG button (GPIO0) as a debounced runtime
    toggle for WiFi, plus a "Turn off WiFi" button on the config page. Replaces
    the boot-hold gating with WIFI_ON_AT_BOOT (power-up state) — press PRG to
    flip it any time. Saves ~80mA when the portal isn't needed.
    [sensor_block_heltec_v3.ino, sensor_onboard_heltec_v3.ino]
2026-06-04 Receiver: detect signal loss faster
    Tighten STALE (30s->15s) and LOST (60s->28s) thresholds so a dropped node
    surfaces in well under half the time, while still riding out a single missed
    packet. Background freshness check bumped to 1s for a prompt transition.
    [receiver_wireless_paper_v1_2.ino]
2026-06-04 Persist WiFi on/off state across reboots
    A node switched off now stays off after a power cycle (saved to NVS), instead
    of coming back on at every boot. WIFI_ON_AT_BOOT becomes the first-run default
    only. Important for deep sleep, where nodes reboot on every wake.
    [sensor_block_heltec_v3.ino, sensor_onboard_heltec_v3.ino]
2026-06-04 Receiver: smaller LOST, fix right-align clip, flash LOST rows
    - LOST now uses a smaller bold font (9pt) so it no longer overruns the edge
    - Right-align accounts for glyph left-bearing (bx) so wide readouts (the "T"
    in LOST, etc.) stop clipping off the right edge
    - LOST rows now flash, inverting every 500ms via the panel's fast-refresh
    mode; CRIT stays a steady inverted bar. Exits fast mode with a clean full
    refresh once nothing is lost.
    [receiver_wireless_paper_v1_2.ino]
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2026-06-04 Receiver: distinguish DEAD battery from LOST connection
    Nodes are powered by the battery they monitor, so a dying battery takes the
    node silent — indistinguishable from a real disconnect. Infer the difference
    from the last reading: a node that goes silent right after a CRIT reading is
    shown as DEAD (steady inverted bar); one that vanishes while still OK/WARN is
    LOST (flashing). No node-side battery required.
    [receiver_wireless_paper_v1_2.ino]
2026-06-04 Fix duplicate row decl; node OLED voltage to 1 decimal
    - Remove the duplicate 'int row = 0;' that broke the receiver build
    - Node OLED voltage now shows one decimal (e.g. 14.7V) instead of two
    [receiver_wireless_paper_v1_2.ino, sensor_block_heltec_v3.ino, sensor_onboard_heltec_v3.ino]
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2026-06-08 Receiver: per-node fuel gauge (SoC % + rough time-to-empty)
    Voltage-based estimate, no extra hardware. Maps pack voltage through a
    per-cell Li-ion discharge curve, rescaled so 100% = full and 0% = CRIT
    (the practical swap point), aware of 4S (OB) vs 6S (BL). Tracks a smoothed
    %/min depletion rate and extrapolates a rough minutes-to-empty.
    Each fresh row now shows e.g. "Cam A 63% ~48m 14.2V". Estimate is
    deliberately approximate (load-dependent) and clears when not depleting.
    Refresh signature quantized (5% / 10-min buckets) to limit e-ink refreshes.
    [receiver_wireless_paper_v1_2.ino]
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2026-06-08 Add web-portal voltage calibration to nodes
    Single-point gain calibration: the config page shows the live reading and
    lets you enter the true voltage from a multimeter. The node computes a gain
    factor (folded into any existing one, sanity-clamped 0.5–2.0) and stores it
    in NVS, so it survives reboots. Reset button restores 1.0. readVoltage()
    applies the factor on both nodes; also registered the logo route on the block
    sketch.
    [sensor_block_heltec_v3.ino, sensor_onboard_heltec_v3.ino]
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2026-06-08 Receiver: live web dashboard
    Long-press the USER button to toggle a WiFi AP ("Brickdup-RX-xxxx", pw
    brickdup) hosting a live dashboard at 192.168.4.1 — a full auto-refreshing
    table of every node (name, voltage, %, time-to-empty, signal bars, status),
    no paging. Short-press still pages the e-ink. Coexists with LoRa RX (separate
    radios). State persists in NVS (default off to save handheld power); e-ink
    shows the AP name in the bottom-left corner while active.
    - / live HTML+JS dashboard (polls /data every 2s)
    - /data JSON snapshot of all nodes + receiver battery
    [receiver_wireless_paper_v1_2.ino]
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2026-06-08 Receiver: hold battery reading while WiFi is up (ADC2 conflict)
    The receiver battery is on GPIO20 (ADC2), which can't be read reliably while
    WiFi is active on the ESP32-S3. Skip sampling while the dashboard is on and
    hold the last good value (battery moves slowly); re-sample immediately when
    the dashboard is turned off.
    [receiver_wireless_paper_v1_2.ino]
2026-06-08 Fix node build: declare readVoltage() before htmlPage uses it
    The forward declaration sat below htmlPage(), which calls readVoltage() to
    show the live reading. Moved it above htmlPage() in both node sketches.
    [sensor_block_heltec_v3.ino, sensor_onboard_heltec_v3.ino]
2026-06-08 Add OTA web firmware update to all units
    Every unit's web portal gets a /update page: upload a compiled .bin with a
    live progress bar, it flashes the spare partition via the built-in Update
    library, verifies, and reboots. Fail-safe (running firmware untouched on a
    bad upload). Linked from each node's config page and the receiver dashboard;
    the page shows which firmware/version it expects. README notes the required
    OTA partition scheme.
    [receiver_wireless_paper_v1_2.ino, sensor_block_heltec_v3.ino, sensor_onboard_heltec_v3.ino]
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2026-06-08 Receiver: persist node roster across reboots (NVS) + clear button
    Roster (permId, type, name, last voltage/status) is saved to NVS, throttled
    to once per ~2min, and reloaded on boot — remembered nodes show as STALE with
    a grace window to re-check-in, so a receiver reboot doesn't lose awareness of
    a dead/silent node. A "Clear node list" button on the dashboard wipes it (with
    confirm). Roster save/load placed after their globals to fix declaration order.
    [receiver_wireless_paper_v1_2.ino]
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2026-06-08 Add triple-tap power off (deep sleep) to all units
    3 quick taps on the button puts a unit into deep sleep (~10-20uA, effectively
    off); a button press wakes it (ext0 wake on GPIO0) and it reboots. Shows "OFF"
    on the display first — the receiver e-ink keeps it visible while asleep.
    Waits for button release before arming wake so it doesn't immediately re-wake.
    Debounce lowered to 80ms so rapid taps register; README documents the controls.
    [receiver_wireless_paper_v1_2.ino, sensor_block_heltec_v3.ino, sensor_onboard_heltec_v3.ino]
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2026-06-08 Revert camera-battery "+"; fix receiver's own-LiPo charging detection
    The "+" is for each unit's internal LiPo, not the camera batteries being
    monitored. Revert the node OLED / packet / receiver per-node charging
    indicators. Fix the receiver's own-battery detection (the threshold was too
    high to catch a slow CC charge): now flags charging when the cell rises vs its
    slow average OR is pinned high (~4.2V on the charger). No hardware charge pin
    exists on the Wireless Paper, so voltage is the only available signal.
    [receiver_wireless_paper_v1_2.ino, sensor_block_heltec_v3.ino, sensor_onboard_heltec_v3.ino]
2026-06-08 Receiver: "+" clears when unplugged (pure rising-trend detection)
    Drop the >4.15V clause that kept "+" stuck on — a full LiPo stays above 4.15V
    long after unplugging. Now "+" shows only while the cell is actually rising,
    sampled every 15s so it clears within ~15-30s of unplugging. Tradeoff: a full
    battery sitting on the charger (flat ~4.2V) won't show "+", which is
    unavoidable without a hardware charge pin.
    [receiver_wireless_paper_v1_2.ino]
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2026-06-09 Bump firmware to v0.5.0 and add CHANGELOG
    First deliberate version bump — FW_VERSION was stuck at 0.1.0 since the
    version display shipped, despite everything added since. CHANGELOG.md rolls it
    all into 0.5.0 and is linked from the README; REFERENCE.md examples updated to
    v0.5.0. Bump FW_VERSION in all three sketches per release going forward.
    [receiver_wireless_paper_v1_2.ino, sensor_block_heltec_v3.ino, sensor_onboard_heltec_v3.ino]
2026-06-09 Receiver: version font a touch smaller (TomThumb 2x)
    Between the too-small TomThumb 1x and the slightly-big 9pt — scale TomThumb to
    2x. Reset text size after so other text is unaffected.
    [receiver_wireless_paper_v1_2.ino]
2026-06-09 Receiver: DEMO_NODES toggle to preview a full 5-node page
    Seeds 5 fake nodes (OK/WARN/CRIT mix, varied signal/%/ETA) and keeps them
    fresh so the page stays populated. Skips roster load/save while in demo so NVS
    isn't polluted. Set DEMO_NODES 0 for normal use.
    [receiver_wireless_paper_v1_2.ino]
2026-06-09 Receiver: place header version dynamically (fix overlap with title)
    Measure the actual BRICKDUP width with getTextBounds and offset the version
    past it, instead of a hardcoded x that was landing inside the bold title. Page
    indicator follows the measured version width.
    [receiver_wireless_paper_v1_2.ino]
2026-06-09 Captive portal: page auto-pops on WiFi connect (all units)
    Add a wildcard DNSServer that resolves every lookup to the AP IP, plus an
    onNotFound catch-all that 302-redirects to the portal/dashboard. The OS
    captive-portal probes (Apple/Android/Windows) then trigger the sign-in sheet,
    so the config page (nodes) / dashboard (receiver) opens automatically on
    connect. DNS starts/stops with WiFi and is serviced in the loop.
    [receiver_wireless_paper_v1_2.ino, sensor_block_heltec_v3.ino, sensor_onboard_heltec_v3.ino]
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2026-06-09 Add sensor_universal: one node, firmware-selectable 4S/6S battery type
    Merges OB + BL into a single sketch with a universal divider (200k/27k, sized
    for 6S with headroom). Battery type (OB 4S / BL 6S) is a runtime setting that
    sets thresholds + the broadcast type:
    • web dropdown on the config page, or
    • LONG-PRESS the PRG button to toggle (short=WiFi, triple=off)
    Stored in NVS. Stable chip-derived id "ND-xxxx" stays constant across type
    changes, and the type rides in the packet — so the receiver needs no changes
    (it already reads type for SoC/display). Added to the CI build.
    [sensor_universal_heltec_v3.ino]
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2026-06-09 Universal OLED: narrow "1" cell + tighter digit gaps
    The 7-seg "1" now uses a narrow cell (just its vertical stroke) instead of
    hugging the right of a full-width cell, so numbers like 16.2 sit balanced.
    GAP tightened back to 4 now that the "1" no longer carries empty left space.
    [sensor_universal_heltec_v3.ino]
2026-06-09 Universal OLED: render the "V" in matching blocky LED style, same line
    Replace the 16pt font "V" with a chunky angled V drawn at full digit height,
    baseline-aligned with the 7-seg digits.
    [sensor_universal_heltec_v3.ino]
2026-06-09 Universal OLED: wider full-height "V"; shorten type to 4S/6S for room
    V was too tall/skinny (12x30) — widen to 20x30 (proper proportions, same
    height as the digits). Shorten the corner type label to 4S/6S (equivalent to
    OB/BL) so the wider V + type both fit on a 3-digit reading.
    [sensor_universal_heltec_v3.ino]
2026-06-09 Universal OLED: lowercase "v" on the baseline (matches the logo's 14.8v)
    Shorter (18px) and bottom-aligned to the digit baseline so it reads as a
    lowercase v rather than a full-height cap V.
    [sensor_universal_heltec_v3.ino]
2026-06-09 Universal OLED: revert to the small font "V" (and OB 4S/BL 6S type label)
    [sensor_universal_heltec_v3.ino]
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2026-06-10 ENCLOSURE: rework node shell to stacked layout (min footprint)
    Per feedback: shrink the footprint to battery-brick proportions.
    LiPo now lies flat on the floor with the Heltec on 13mm corner towers
    directly above it (battery JST faces down — short lead run). Outer
    shrinks from ~75x68x20 to ~74x35x30 (+ corner screw ears); length is
    floored by the 50.2mm board + a 15mm LEMO bay.
    Internal bosses had no room in the narrow shell, so the lid screws
    into four external ear posts. LEMO enters low so its tail runs under
    the board's east end; rim cradle locates the PCB edges; header notes
    the dry-fit checks (LEMO tail vs buck, bottom pin headers, LiPo side
    clearance).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
    [node_enclosure.scad]
2026-06-10 ENCLOSURE: captive printed button plungers (no exposed PCB)
    PRG/RST are no longer bare holes over the board: each button gets a
    guide tube under the lid and a small printed piston, dropped in from
    the inside before the lid is screwed on. A 45-degree flare seats on
    the tube rim so the piston is captive (~0.2mm float); the tactile
    switch's own spring returns it. Both cones are 45 degrees, so the
    pistons print supportless, tip-up.
    part="both" lays out the two pistons next to the lid; part="plunger"
    renders one; plungers=false falls back to plain access holes. Throw
    depends on btn_top (button cap height above the PCB) - tagged MEASURE.
    [node_enclosure.scad]
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2026-06-11 ENCLOSURE: measured dims (comp_h 4 etc) + low-lid plunger fixes
    Ryan's caliper pass: comp_h 10 -> 4 (box drops to ~73x52x24), OLED
    window and PRG/RST positions corrected, SMA gets its own sma_z (14).
    The lower lid broke three things, fixed here:
    - The plunger flange stack (4.8mm) no longer fit the 4.3mm between
    button top and lid underside. Slimmed the flange (d8, 0.4 land) and
    tube_len is now DERIVED from headroom (leaves 0.3mm captive float),
    with an echo warning when the lid is too low for the flange.
    - Vents poked above the shorter wall top; defaults dropped to z13/h7.
    - The lid's locating lip crossed the USB plug path; the lip is now
    notched over the port, and the chamfer shrun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
    [node_enclosure.scad]
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2026-06-11 ENCLOSURE: board clicks into its tray (lip + snap nubs)
    Per feedback: the tray walls stood ~2mm proud of the PCB doing only
    lateral location. They now stop 0.3mm above the board top, and the
    board is retained by a continuous lip on the south rib plus two
    chamfered snap nubs on the north rib (slits flank each nub so its rib
    section flexes ~0.5mm). Assembly: tilt the south edge under the lip,
    press the north edge down to click. Snug, no rattle, removable with
    a spudger. Board seat height is unchanged, preserving the underside
    JST and LEMO-tail clearances.
    [node_enclosure.scad]
2026-06-11 ENCLOSURE: board length measured at 48mm (tray 51 -> 49)
    Clarified feedback: "2mm shorter" meant the tray's long dimension.
    pcb_l 50.2 -> 48.0, so the pocket is 49mm and the shell shrinks to
    ~71x54x24. Everything east (bay rib, bay, LEMO) follows. The LEMO
    tail margin to the LiPo end stop tightens to ~1mm — header note
    updated with the real limit (~21mm body before bay_l must grow).
    [node_enclosure.scad]
2026-06-11 ENCLOSURE: LEMO body measured — 12mm behind flange, bay shrinks to 12
    The body intrudes only 10mm past the 2mm wall, so it stays entirely
    inside the east bay: the under-board clearance worry is gone and the
    bay drops 14 -> 12mm. Leads bend in the remaining 2mm or route
    through the bay rib gap under the board. Outer ~69x54x24.
    [node_enclosure.scad]
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2026-06-11 ENCLOSURE: restore full-height tray walls; chamfer the lip mouth
    The "2mm shorter" request had been misread as wall height and cut the
    cradle walls to 0.3mm above the PCB; the later length correction
    (51->49) never restored them, leaving no clearance to get the board
    under the retention lips. Walls are back to 2mm past the PCB top
    (proper lateral holding), and the south lip now has a 45-degree
    chamfered underside: its mouth sits ~1.7mm above the board for easy
    tilt-in, wedging snug at the wall face once seated. The north snap
    nubs keep their flat underside 0.3mm over the board, now partway up
    the restored wall. Everything stays 45-degree/supportless.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
    [node_enclosure.scad]
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2026-06-11 ENCLOSURE: tab_gap 18 -> 21mm for extra antenna-tab clearance
    A little wider hurts nothing: the board is retained by the south lip
    and north snap nubs, so the bay rib's east cradle is secondary — the
    ~2.7mm corner segments still locate the board fine.
    [node_enclosure.scad]
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2026-06-11 ENCLOSURE v3: post-print fit pass from the v2 test print
    The v2 print fit well except the plungers pressed their buttons when
    the lid was screwed tight (fine with it loose). That symptom means
    the real button cap sits ~1.5mm taller than the 1.7mm btn_top guess:
    the piston's flange hit the tube rim before the tip could back off
    the switch. Fixes:
    - btn_top 1.7 -> 3.2 (from fit; VERIFY with calipers). The derived
    tube_len drops to 0 (bore guides in the lid plate alone).
    - Flange stack slimmed (flange_d 8 -> 7.4, land 0.4 -> 0.3) so the
    piston fits the reduced headroom; fully pressed-in tip floor is now
    0.8mm above the button, so a seated lid can never hold it pressed.
    - Tray length -1mm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
    [node_enclosure.scad]
2026-06-11 ENCLOSURE: open up the battery pocket to the real cell (v2 print fit)
    Cell measured 41.39 x 25.15 x 10.25 — the old pocket pinched it: the
    4mm corner towers left only a 40mm clear span and the end-stop rib
    crowded the lead end. Per Ryan's fix: end stop deleted (cell is tape-
    retained, leads run free to the bay-rib gap and into the bay), towers
    slimmed to 3mm wide and pushed flush against the west rim / bay rib,
    giving a 42mm clear span. LiPo params updated to the measured dims.
    [node_enclosure.scad]
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2026-06-12 ENCLOSURE v5 (wip): swap LEMO/SMA on the east wall; LEMO hole 8.9mm
    The LEMO's 10mm body left no working room behind it at the centreline
    spot (the bay rib sat 2mm off its rear). Swapped with the SMA: the
    LEMO now sits at the SE position where its rear lines up with the
    open south channel — leads run straight toward the buck with no sharp
    bend and there's length behind it for soldering. The SMA (just a
    pigtail nut) takes the centreline-low spot. LEMO panel hole corrected
    to the measured 8.9mm (was the 12mm 1B guess); nut clearances to the
    SE boss and floor checked. v5 stays untagged until it prints.
    [node_enclosure.scad]
2026-06-12 ENCLOSURE v5 (wip): keyed connector holes + taller nub wall
    Both panel connectors get their measured anti-rotation flats: LEMO is
    a double-D (8.9 dia, 8.2 across flats, flats top/bottom), SMA gets a
    single bottom flat (6.5 dia, 5.75 flat-to-round). Cut as cylinder/
    cube intersections.
    Tray: the north (snap-nub) wall now runs 1.5mm taller than the south
    side — with the battery pushing the board up from below, the board
    edge stays inside the wall instead of popping over the top. Nub
    heights unchanged, so the click-in feel is the same.
    [node_enclosure.scad]
2026-06-12 ENCLOSURE v5 (wip): raise the snap nubs +1.5 to the real ride height
    With the battery + underside JST under it, the board rides higher
    than the bare-board model assumed, so the nubs (pinning at +0.3 over
    nominal board top) fought the install. Their flat underside moves to
    +1.8, lead-in top to +3.0 — just under the raised wall top.
    [node_enclosure.scad]
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2026-06-18 ENCLOSURE v7: SMA flat 5.9, LEMO scooted toward the south wall
    Ryan's fit tweaks: sma_flat 5.75 -> 5.9 (re-measured), and lemo_y
    14 -> 12.5 (LEMO moved closer to the south wall). Synced the now-
    stale comments (LEMO note no longer says "nudged up"; SMA inline
    comment 5.75 -> 5.9; lemo_flat note reflects the v6 left/right flats).
    [node_enclosure.scad]
2026-06-18 ENCLOSURE v8: revert LEMO scoot (lemo_y back to 14)
    The v7 move toward the south wall left no clearance for the LEMO
    panel nut to spin on the back of the connector. Back to lemo_y = 14.
    SMA flat (5.9) stays.
    [node_enclosure.scad]
2026-06-18 ENCLOSURE v9: deepen east bay (bay_l 12 -> 18) for LEMO wire clearance
    The LEMO's rear solder cups/wires were crowding the board/tray. Rather
    than move the tray (which would drag the west-referenced USB, button,
    and OLED holes with it), grow the east bay: only the east wall with
    the LEMO/SMA moves, lid and board stay put. ~8 mm now sits behind the
    connector before the bay rib. Box grows ~6 mm in length (~74x54x24).
    [node_enclosure.scad]
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
